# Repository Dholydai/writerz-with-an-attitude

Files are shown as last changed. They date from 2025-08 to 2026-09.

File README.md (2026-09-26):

# writerz-with-an-attitude
Human-factored Post-Mechanical writing instruments designed for and approved by 'Writerz With an Attitude'.

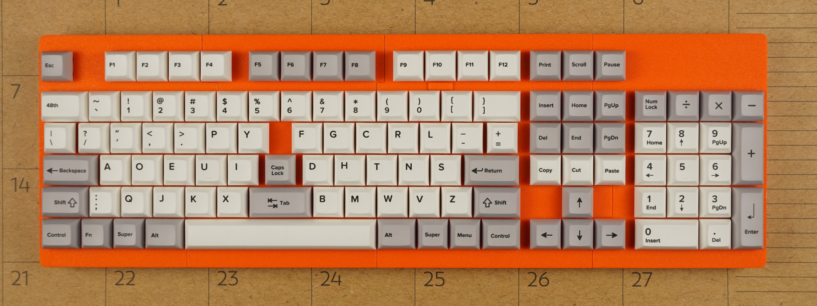
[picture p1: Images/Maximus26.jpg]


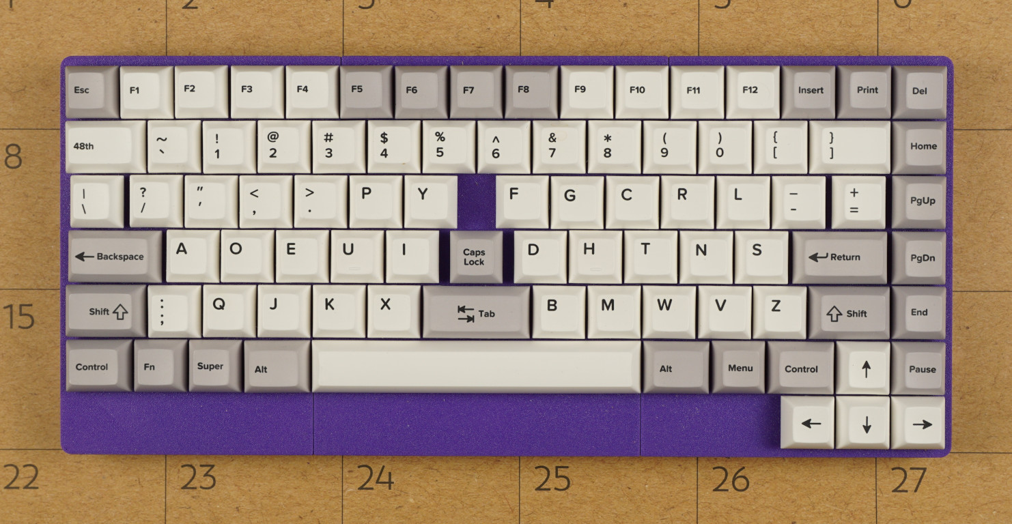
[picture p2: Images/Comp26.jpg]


Why are nascent writers, born in the third decade of the 21st century, being shackled to a 152-year-old 19th-Century mechanical typewriter interface?

I have used a Dvorak keyboard for thirty-five years. After two decades of typing, bad pains developed in my left hand and wrist. Analyzing 
my breakdown, I concluded that the physical layout of keys on conventional keyboards forces unnatural movements.

The typewriter keyboard is injurious, as evidenced by the long history of 'typists' developing carpal tunnel syndrome, including myself.

I designed the 'Dvorak 2026' to place the keys where the fingers of my two hands expect them to be. No more pain, writing is fun.

I contend that the Post-Mechanical variants establish a 'Nuevo Teclado Universal' standard. These human-factored designs will fit in currently produced
laptop PC cases. The forty-eight character keys make the keyboards ISO compliant, compatible with European languages.

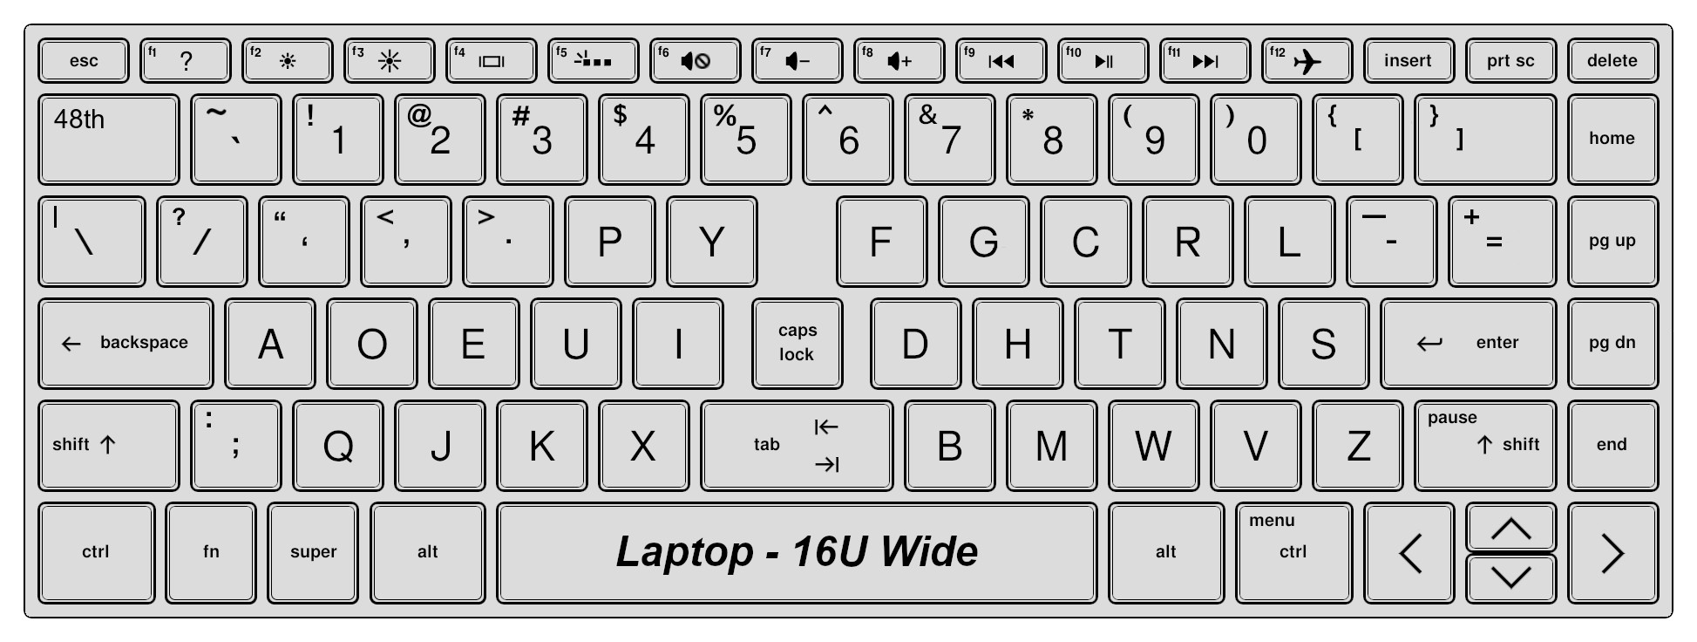
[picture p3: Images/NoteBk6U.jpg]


I have created ISO compliant firmware, and designed Windows drivers for six European languages, so far. Work on Lixux keyd configurations will
begin. Apple drivers are not my wheelhouse. Collaboration from those who can write Apple drivers is expected.

Single-hand writers should have use of modern writing instruments. After World War 2 ended, LCDR Dvorak designed two practical single-hand letter 
schemes for the typewriter that enabled disabled veterans to type comfortably.

My new compact single-hand keyboard designs have a few notable tweaks, but do not stray far from the original designs. Both variants now share 
the same letter scheme. The left-hand and right-hand keyboards are mirror images of each other.

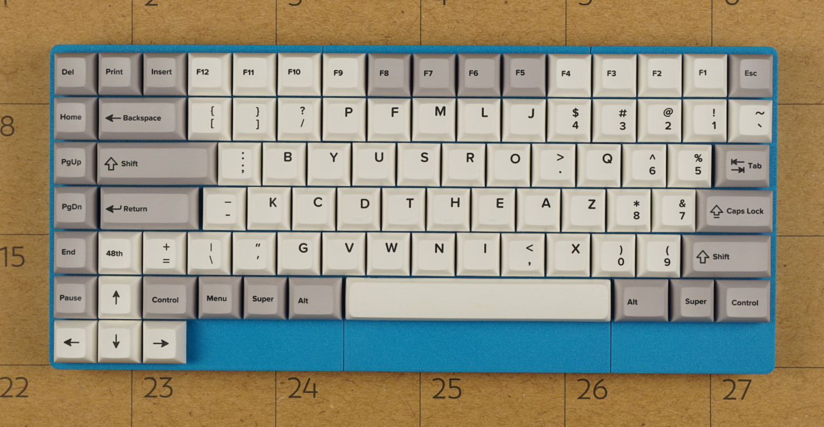
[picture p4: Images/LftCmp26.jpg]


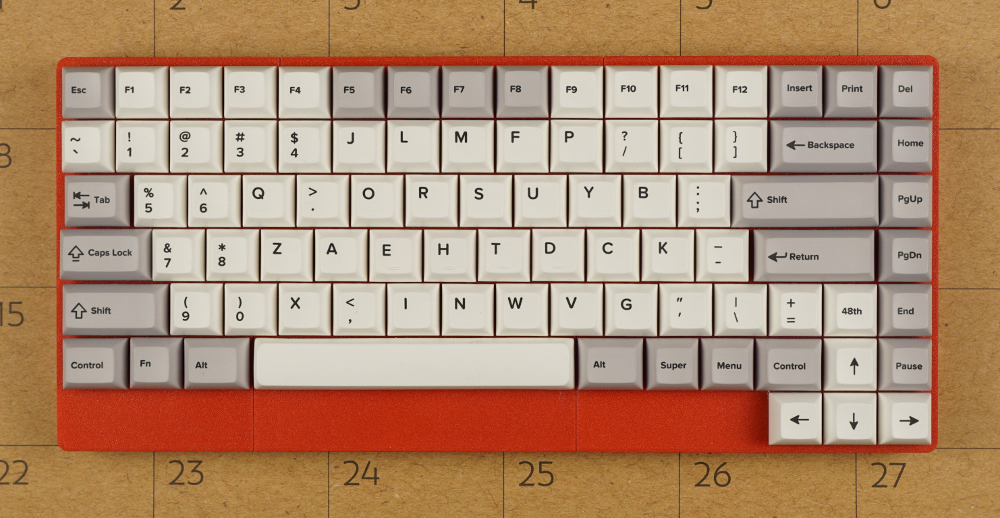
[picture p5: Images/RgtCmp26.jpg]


Quality of key switches:

Cherry MX switches have great quality. Never had a problem with them. I build all of my keyboards with Cherry switches. Less costly switches from other
manufacturers that I have tried are not shaped consistantly. Those switches would not fit the tight tolerances of my case tops. The stems tilted this
way and that way.

Availability of keycap sets:

I have been subsituting common keycaps sizes for the exotic sizes required. I bought large XDA keycap sets, and relabeled selected keycaps with 
keyboard stickers as needed.

Finding a 6U spacebar is difficult. My source makes spacebars with the stem 1\2U offset. I have designed alternate case top sections to accommodate that
spacebar. My PCBs have a dual position switch footprint to accommodate either centered or offset spacebar switch.

YUZU... In May 2025 I found a die-sub keycap manufacturer that makes one-off custom sets. The Prusa orange Maxmius above is populated by one of the many
austere sets I have created. I have designed and purchased nine keycaps sets from YUZU, including Spanish(Spain), Portuguese(Brazil), and BÉPO(France).

YUZU custom keycaps will make any die-sub keycap set that your heart desires. Common sizes still have to be sustituted. Being able to choose keycap 
sizes, colors, and legends is wonderful. Love the new Penguin Slide Belly (PBS) profile keycaps. Great price and quality.

The French, Spanish, and Brazilian keyboards were built in late August 2026.

3D printer problems:

The first Maximus case would not sit flat on a desktop. After a month of struggle to solve the problem, I reluctantly concluded that:

1. My Voron Trident 350 cannot print case top sections with enough quality. The X- to Y-axis geometry is not consistently 90 degrees.
2. This problem is not Voron Designs' shortcoming, it is intrinsic to all Core-XY printers. This is due to the quick changes of direction that temporarily stretch the long XY belts during operation; that slop gets worse as printer size increases.
3. 'Bed slingers' use much shorter belts, they do not have this built-in fault.

My Prusa MK3.5 has a new companion... a Prusa MK4S. The new printer makes parts that match-up perfectly with the MK 3.5 parts. Print times for a case
bottom section changed dramatically: from 3hs 15 mins to 1 hr 45 mins. I am now a committed Prusa fanatic.

Link to my repo of custom KiCad libraries: [MX Switch Custom](https://github.com/Dholydai/mx-switch-custom)

Ronald Earl Walker - Inventor of the Post-Mechanical Keyboard

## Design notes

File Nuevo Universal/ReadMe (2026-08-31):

Nuevo Universal Keyboard:

The Dvorak typewriter keyboard letter scheme is designed for writing using two-hands. It is apposite for writing any language that uses the Latin, Cyrillic or Greek script.

Note: The US(English) Post-Mechanical keyboard is hardwired to use the native QWERTY driver. Users should not install the America-ISO driver,

Note: Linux OS users of the US(English) Post-Mechanical will use the native US-QWERTY driver.

The US English ISO driver was written to facilitate developing European language drivers (the locations of the '[ ]' and '- =' key sets are swapped).

The Post-Mechanical Dvorak 2025 keymap has 48 character keys. This makes it compatible with ISO keyboards.

I have created and tested Windows drivers for several European languages. Linux drivers will be developed next, Apple is not my wheelhouse.

Ronald Earl Walker

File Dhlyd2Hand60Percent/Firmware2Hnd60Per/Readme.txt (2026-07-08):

The Post-Mechanical Ambidextrous Sixty has three status LEDs mounted in MX switches. The 'Caps Lock' works as as expected, the Left- and Right-Hand 'Fn' key LEDS do not.

The layers (Standard, Left-Hand and Right-Hand) are functioning correctly. The right 'Fn' key selects Left-Hand and toggles back to Standard when pressed again.
Visa versa for the left 'Fn' key. Good to go.

The status LEDs do light up, but not in current operation as status indicators by the firmware. KMK can surely be configured or tweaked to do the job.

I am not a coder. I cannot figure out how make this work. KMK does provide for 'Layer Status' indication using the background RGB LEDs, not discrete LEDS.

I build writing instruments, not entertainment centers. RGB backgroud LEDs are candy that is craved by ADHD lemmings in need of stimulus.

Collaboration would be greatly appreciated.

Ronald Earl Walker

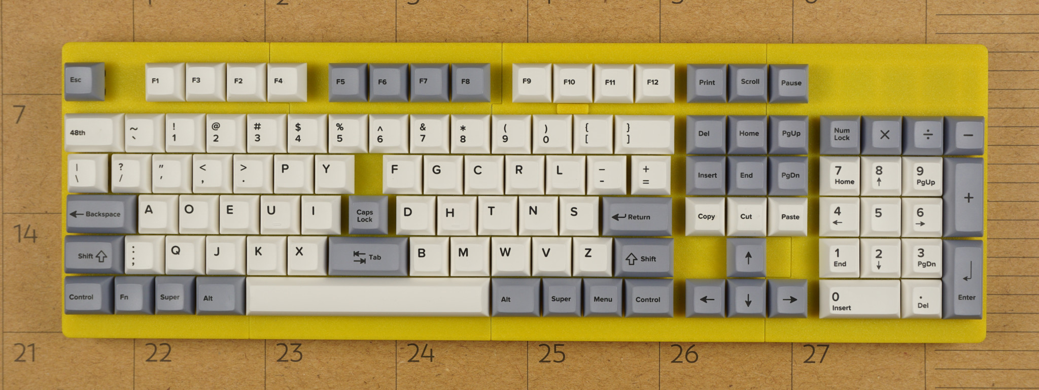
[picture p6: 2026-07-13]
Images/Maximus26B.jpg

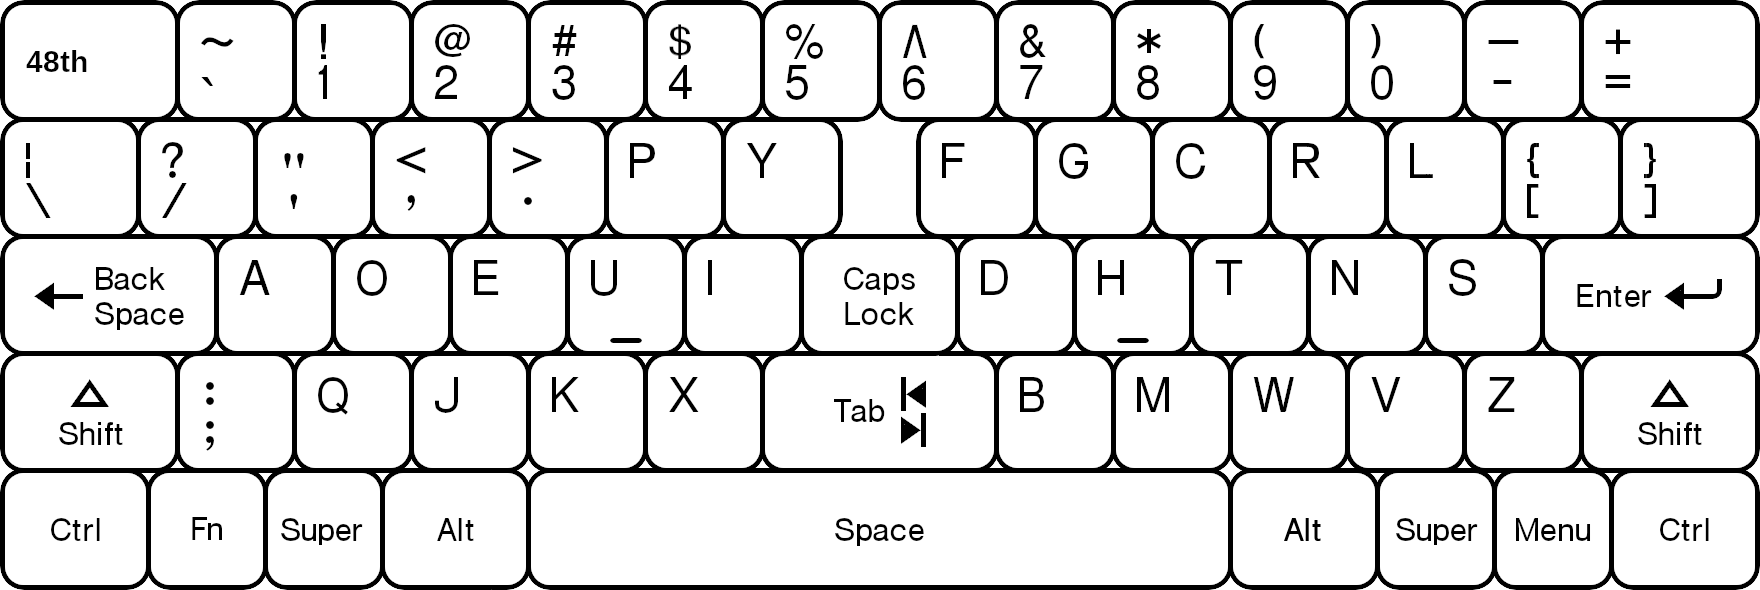
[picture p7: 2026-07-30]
Nuevo Universal/America-ISO/BlkQX1-ENGiso.png

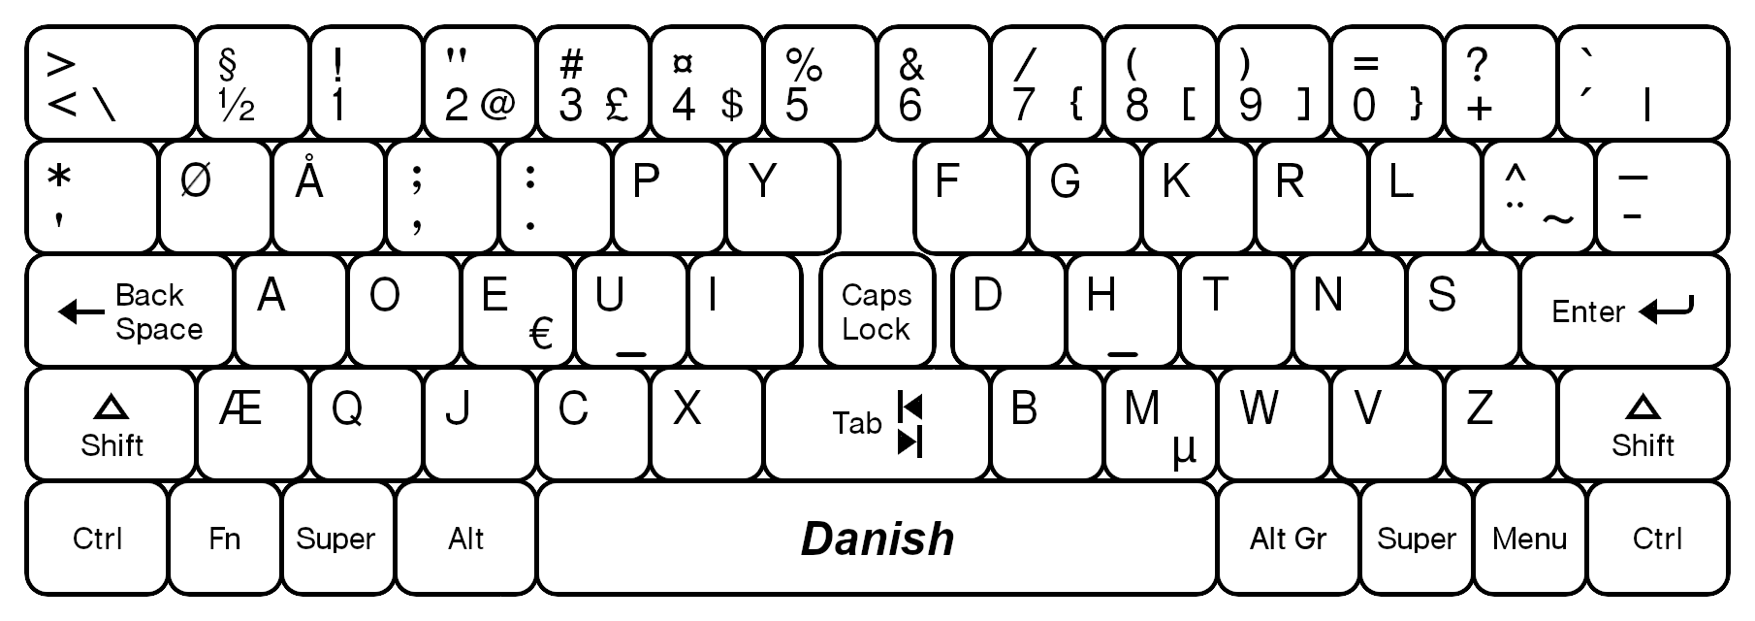
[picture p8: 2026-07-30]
Nuevo Universal/Denmark/BlkQX1-Dane.png

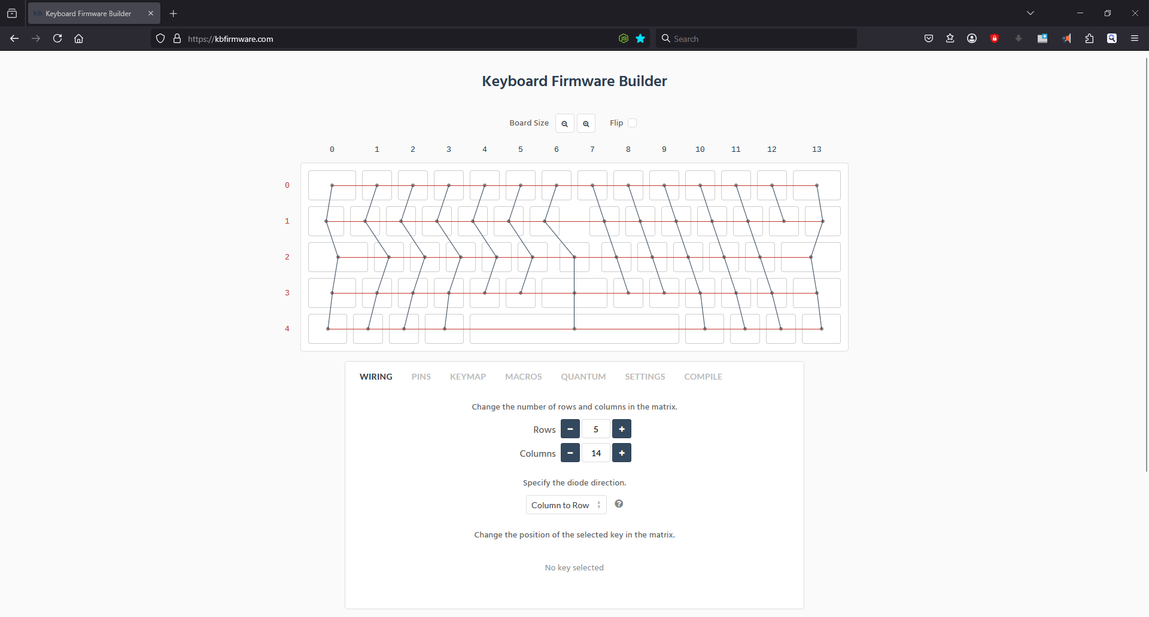
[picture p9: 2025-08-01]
Matrix/Dhlyd2Hnd60.png

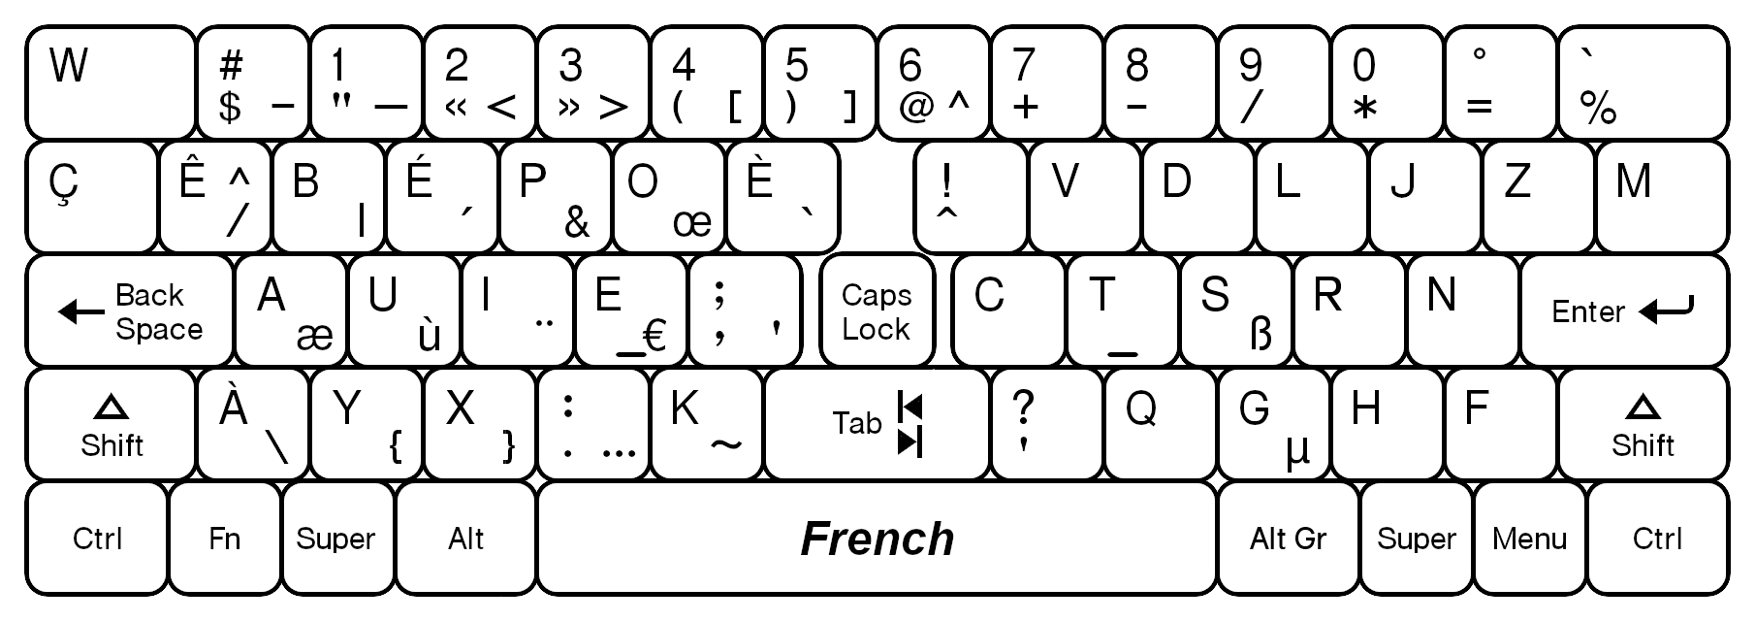
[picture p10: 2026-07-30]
Nuevo Universal/France-BÉPO/BlkQX1-French.png

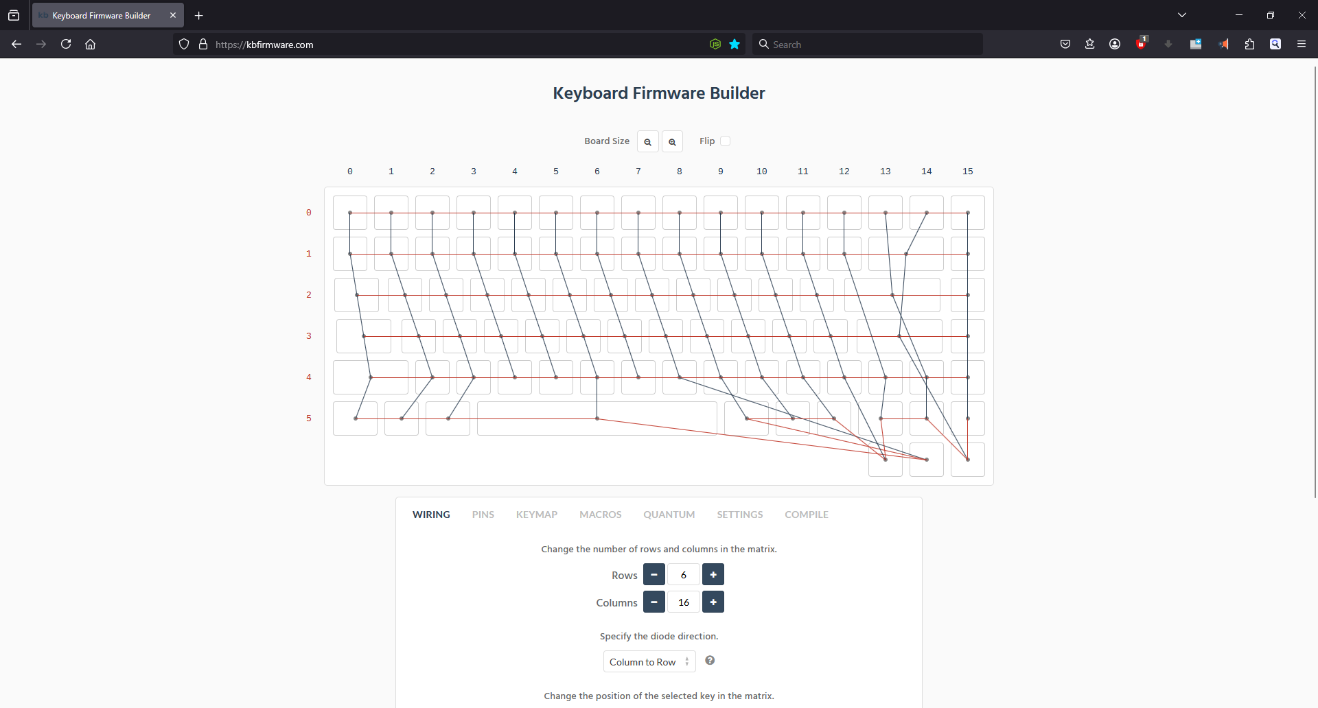
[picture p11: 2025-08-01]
Matrix/DhlydRightCmp.png

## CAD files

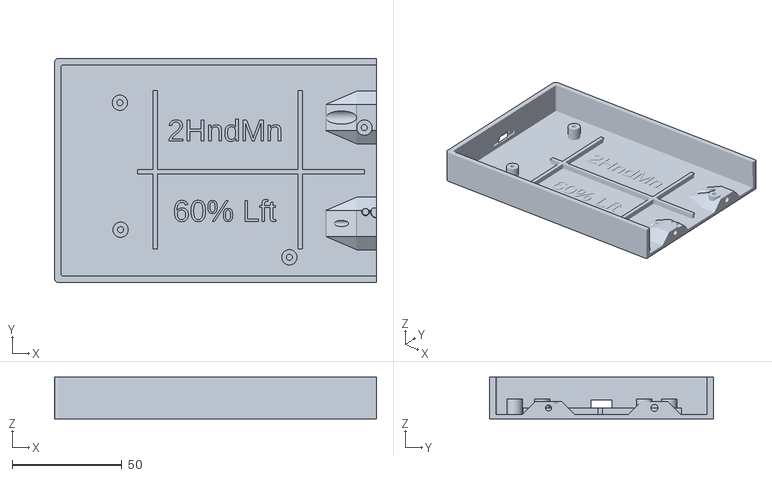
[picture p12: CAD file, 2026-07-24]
Dhlyd2Hand60Percent/Case2Hnd60Per/Minimal/SixtyMiniLft.stl
146.7 x 102.2 x 19.0

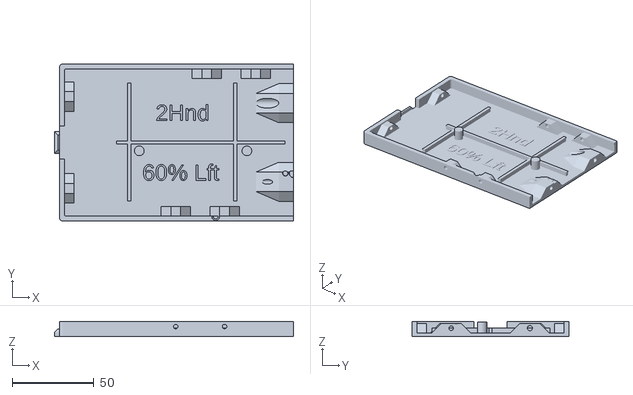
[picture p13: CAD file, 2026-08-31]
Dhlyd2Hand60Percent/Case2Hnd60Per/Stl/SixtyBtmLft.stl
146.6 x 96.2 x 9.00

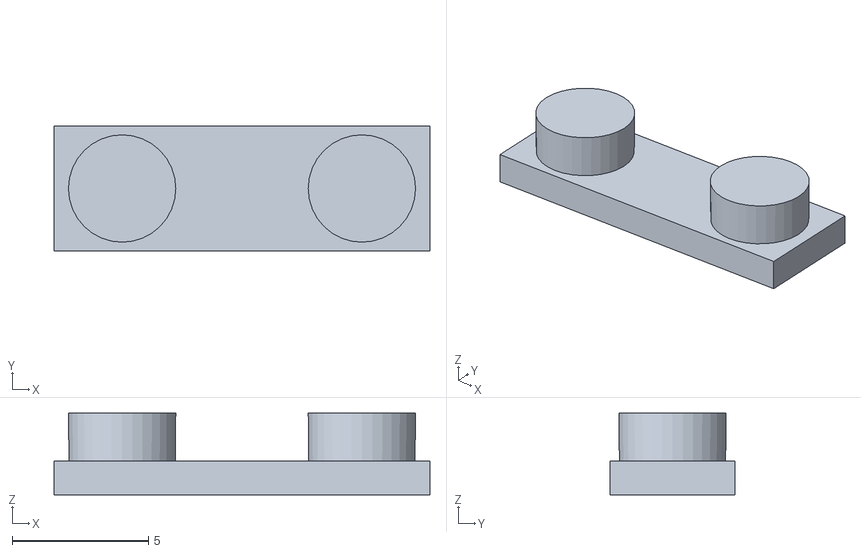
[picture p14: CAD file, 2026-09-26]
Dhlyd2HandCompact/Case2HndComp/Stl/ResetRunCvrCmp.stl
13.8 x 4.60 x 3.00

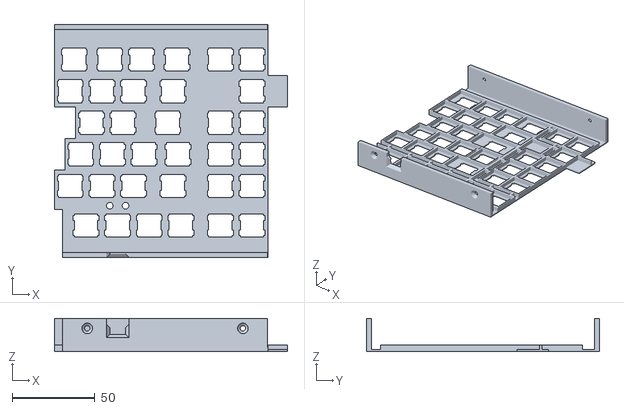
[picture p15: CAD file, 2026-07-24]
Dhlyd2HandMaximus/Case2HndMaximus/Stl/Max2HndTopMid2.stl
140.5 x 140.4 x 20.0

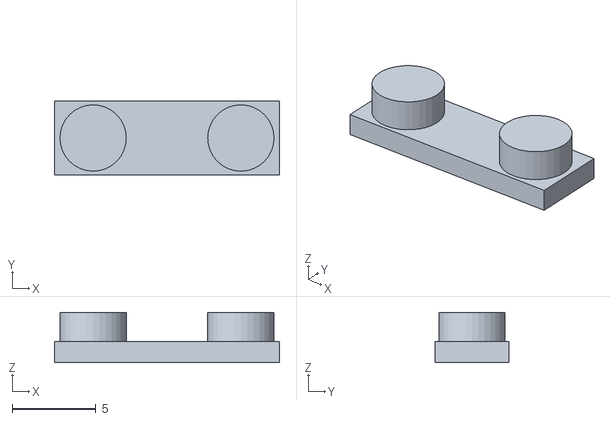
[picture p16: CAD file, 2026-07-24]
DhlydLeftCompact/CaseLeftHndComp/Stl/ResetRunCvrLR.stl
13.4 x 4.40 x 3.00

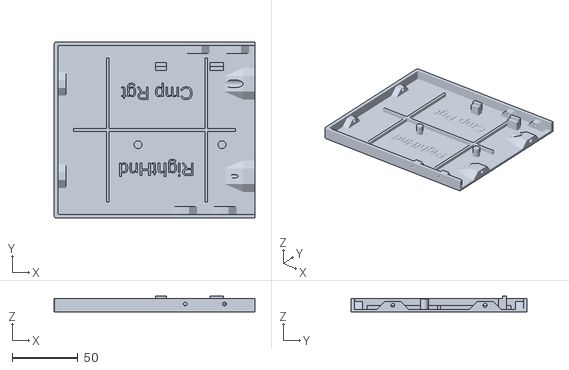
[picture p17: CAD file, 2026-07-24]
DhlydRightCompact/CaseRightHndComp/Stl/CompRightBtmRgt.stl
153.1 x 134.3 x 12.0

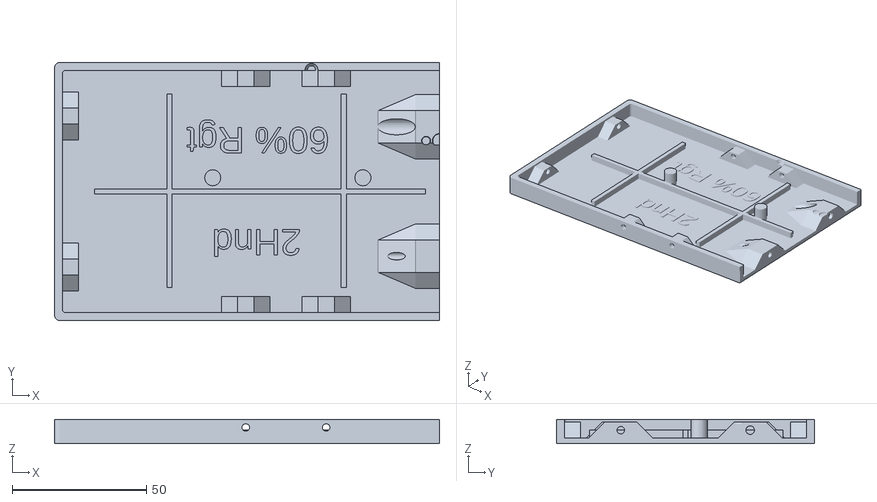
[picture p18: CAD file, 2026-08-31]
Dhlyd2Hand60Percent/Case2Hnd60Per/Stl/SixtyBtmRgt.stl
143.6 x 96.2 x 9.00

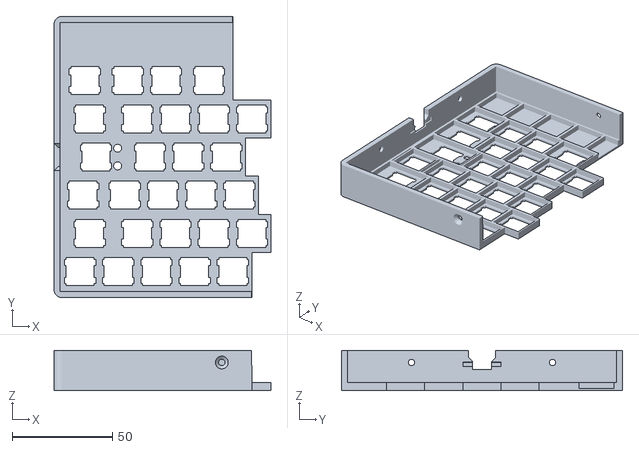
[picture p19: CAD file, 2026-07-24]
Dhlyd2HandCompact/Case2HndComp/Stl/Comp2HndTopLft.stl
108.3 x 140.4 x 20.0

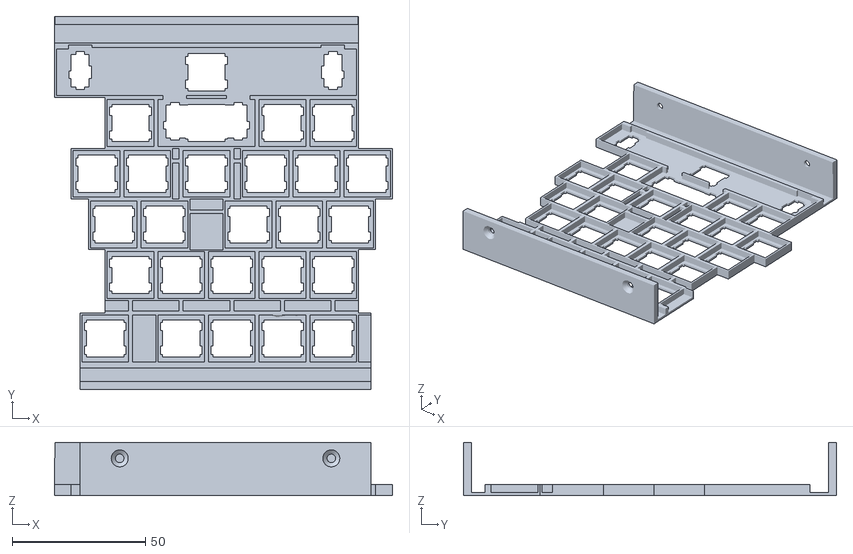
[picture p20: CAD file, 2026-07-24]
Dhlyd2HandMaximus/Case2HndMaximus/Stl/Max2HndTopMid1_Center.stl
127.1 x 140.3 x 20.0

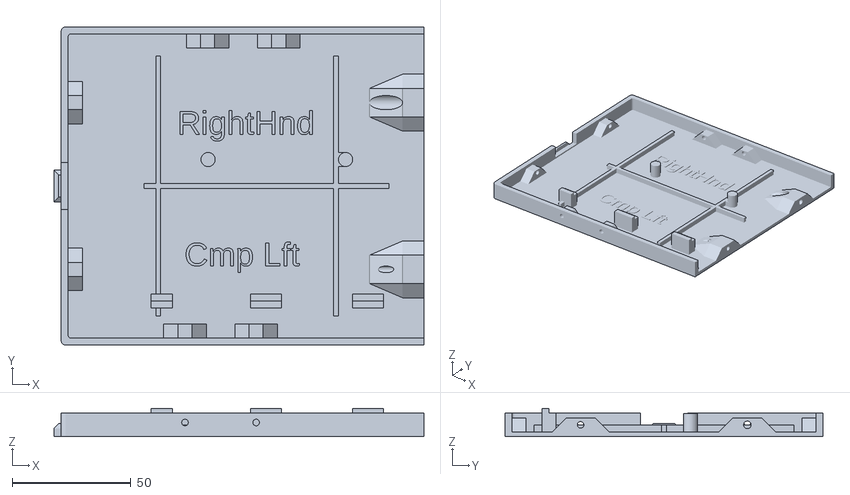
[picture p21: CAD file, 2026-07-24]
DhlydRightCompact/CaseRightHndComp/Stl/CompRightBtmLft.stl
156.1 x 134.4 x 12.0

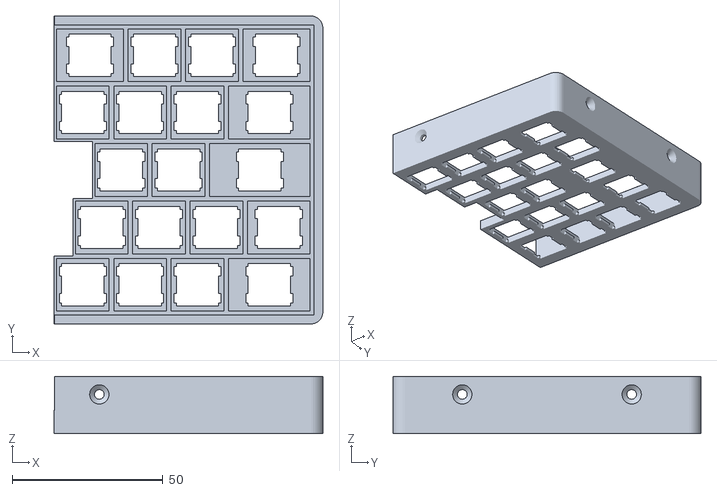
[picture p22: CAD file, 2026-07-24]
Dhlyd2Hand60Percent/Case2Hnd60Per/Stl/SixtyTopRgt.stl
89.2 x 102.2 x 19.0

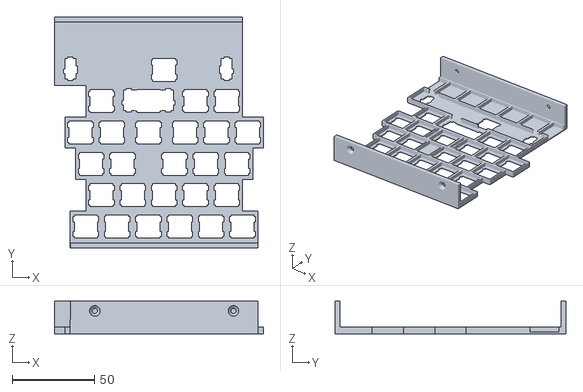
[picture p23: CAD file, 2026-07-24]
Dhlyd2HandCompact/Case2HndComp/Stl/Comp2HndTopMid_Offset.stl
127.1 x 140.4 x 20.0

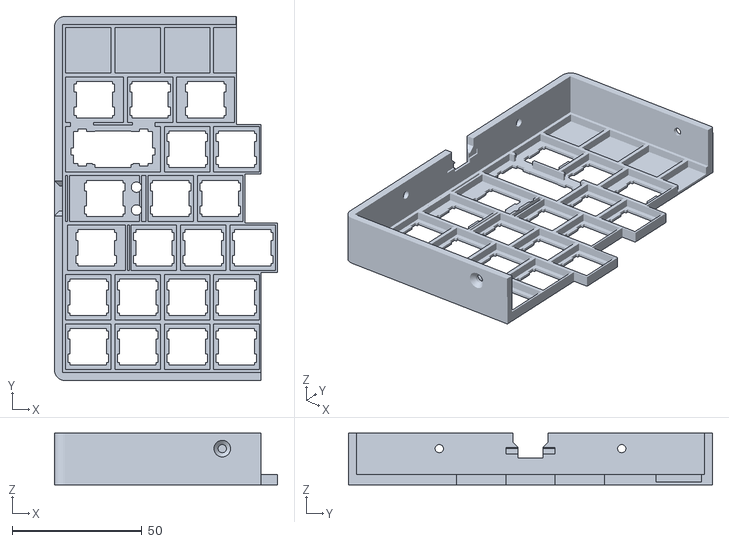
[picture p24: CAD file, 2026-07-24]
DhlydRightCompact/CaseRightHndComp/Stl/CompRightTopLft.stl
86.0 x 140.4 x 20.0

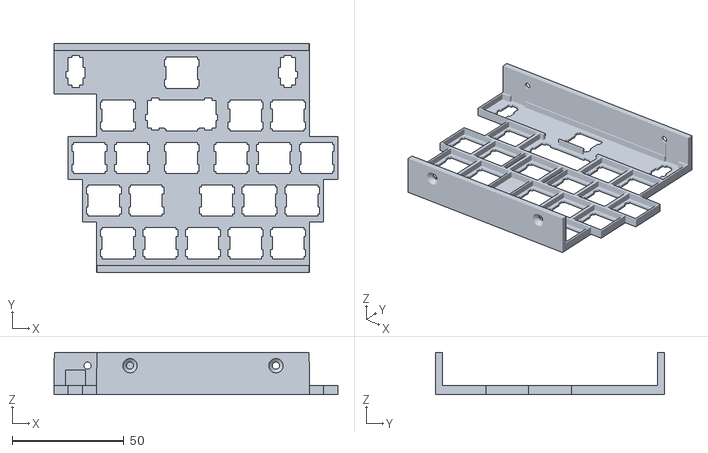
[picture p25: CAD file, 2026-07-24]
Dhlyd2Hand60Percent/Case2Hnd60Per/Stl/SixtyTopMid_Center.stl
127.1 x 102.2 x 19.0

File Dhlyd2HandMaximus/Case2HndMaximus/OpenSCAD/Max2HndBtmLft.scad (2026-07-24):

// Dholydai: 05 May 2025 10mm Z and X=143.20833...
// Add 0.1mm to the top & bottom screw holder's X axis, compensating for shrinkage.
// Add shallow angle cuts to the sidewall butt faces, compensating for printer artifacts.
// Reduced ribs Z 10 Jul 2026

translate([51,36,0])
rotate([0,0,0])
linear_extrude(2.6)
text("Max Lft",size=10,font="Microsoft Sans Serif");
translate([57,91,0])
rotate([0,0,0])
linear_extrude(2.6)
text("2Hnd",size=10,font="Microsoft Sans Serif");

//BASE
$fn=32;

difference(){
//Deck
    union() {
        translate([2,2,0])
            cube([141.2,130.35,2]);
        translate([2,0,0])
            cube([141.2,2,2]);   
        translate([2,132.35,0])
            cube([141.2,2,2]);
        translate([0,2,0])
            cube([2,130.35,2]);    
        translate([2,2,0])
            cylinder(h=2,r1=2,r2=2);
        translate([2,132.35,0])
            cylinder(h=2,r1=2,r2=2);
//Sidewall
translate([0,2,2])
    cube([3,130.35,8]);
translate([2,131.35,2])
    cube([141.2,3,8]);
translate([2,0,2])
    cube([141.2,3,8]);
//SW Corners Outside   
translate([2,2,6])
    rotate([0,0,180]){
    rotate_extrude( angle=90)
        translate([1,0,0])
            square([2,8], center=true);
}
translate([2,132.35,6])
    rotate([0,0,90]){
    rotate_extrude( angle=90)
        translate([1,0,0])
            square([2,8], center=true);
}        
//SW Corners Inside   
translate([4,4,6])
    rotate([0,0,180]){
    rotate_extrude( angle=90)
        translate([2,0,0])
            square([2,8], center=true);
}
translate([4,130.3125,6])
    rotate([0,0,90]){
    rotate_extrude( angle=90)
        translate([2,0,0])
            square([2,8], center=true);        
    }
//Screw Reenforcement
//Side
translate([3,41,2]){
    rotate([0,0,270])
             union() { 
            translate([6,0,0])
                cube([6,6,6]);            
polyhedron(points=[[0,0,0], [6,0,0], [6,6,0], [0,6,0], [6,0,6], [6,6,6]],
    faces=[[0,1,2,3],[1,4,5,2],[0,3,5,4],[0,4,1],[3,2,5]]
    );
polyhedron(points=[[12,0,0], [18,0,0], [18,6,0], [12,6,0], [12,0,6], [12,6,6]],
    faces=[[0,1,2,3],[1,4,5,2],[0,3,5,4],[0,4,1],[3,2,5]]
    );
  }
}          
translate([3,111.3125,2]){
    rotate([0,0,270])
             union() { 
            translate([6,0,0])
                cube([6,6,6]);            
polyhedron(points=[[0,0,0], [6,0,0], [6,6,0], [0,6,0], [6,0,6], [6,6,6]],
    faces=[[0,1,2,3],[1,4,5,2],[0,3,5,4],[0,4,1],[3,2,5]]
    );
polyhedron(points=[[12,0,0], [18,0,0], [18,6,0], [12,6,0], [12,0,6], [12,6,6]],
    faces=[[0,1,2,3],[1,4,5,2],[0,3,5,4],[0,4,1],[3,2,5]]
    );
  }
}
//SR Fore A
translate([62.225,3,2]){
    rotate([0,0,0])
             union() { 
            translate([6,0,0])
                cube([6,6,6]);            
polyhedron(points=[[0,0,0], [6,0,0], [6,6,0], [0,6,0], [6,0,6], [6,6,6]],
    faces=[[0,1,2,3],[1,4,5,2],[0,3,5,4],[0,4,1],[3,2,5]]
    );
polyhedron(points=[[12,0,0], [18,0,0], [18,6,0], [12,6,0], [12,0,6], [12,6,6]],
    faces=[[0,1,2,3],[1,4,5,2],[0,3,5,4],[0,4,1],[3,2,5]]
    );
  }
}
//SR Fore B          
translate([92.225,3,2]){
    rotate([0,0,0])
             union() { 
            translate([6,0,0])
                cube([6,6,6]);            
polyhedron(points=[[0,0,0], [6,0,0], [6,6,0], [0,6,0], [6,0,6], [6,6,6]],
    faces=[[0,1,2,3],[1,4,5,2],[0,3,5,4],[0,4,1],[3,2,5]]
    );
polyhedron(points=[[12,0,0], [18,0,0], [18,6,0], [12,6,0], [12,0,6], [12,6,6]],
    faces=[[0,1,2,3],[1,4,5,2],[0,3,5,4],[0,4,1],[3,2,5]]
    );
  }
}
//SR Aft A
translate([89.755,131.35,2]){
    rotate([0,0,180])
             union() { 
            translate([6,0,0])
                cube([6,6,6]);            
polyhedron(points=[[0,0,0], [6,0,0], [6,6,0], [0,6,0], [6,0,6], [6,6,6]],
    faces=[[0,1,2,3],[1,4,5,2],[0,3,5,4],[0,4,1],[3,2,5]]
    );
polyhedron(points=[[12,0,0], [18,0,0], [18,6,0], [12,6,0], [12,0,6], [12,6,6]],
    faces=[[0,1,2,3],[1,4,5,2],[0,3,5,4],[0,4,1],[3,2,5]]
    );
  }
}
//SR Aft B         
translate([119.755,131.35,2]){
    rotate([0,0,180])
             union() { 
            translate([6,0,0])
                cube([6,6,6]);            
polyhedron(points=[[0,0,0], [6,0,0], [6,6,0], [0,6,0], [6,0,6], [6,6,6]],
    faces=[[0,1,2,3],[1,4,5,2],[0,3,5,4],[0,4,1],[3,2,5]]
    );
polyhedron(points=[[12,0,0], [18,0,0], [18,6,0], [12,6,0], [12,0,6], [12,6,6]],
    faces=[[0,1,2,3],[1,4,5,2],[0,3,5,4],[0,4,1],[3,2,5]]
    );
   }
 }      
}
//Screw Holes Side
#translate([-1,32,6]){
    rotate([0,90,0]){
         cylinder(d=2.8,h=12);      
      }
}
#translate([-1,102.3125,6]){
    rotate([0,90,0]){
         cylinder(d=2.8,h=12);      
      }
}
//Screw Holes Fore A
#translate([71.225,-1,6]){
    rotate([-90,0,0]){
         cylinder(d=2.8,h=12);      
      }
}
//SH Fore B
#translate([101.225,-1,6]){
    rotate([-90,0,0]){
         cylinder(d=2.8,h=12);      
      }
}
//Screw Holes Aft A
#translate([80.755,136,6]){
    rotate([90,0,0]){
         cylinder(d=2.8,h=12);
    }
}
//SH Aft B     
#translate([110.755,136,6]){
    rotate([90,0,0]){
         cylinder(d=2.8,h=12);      
      }
    }
//Shallow angle sidewall cuts
//Cutter Fore (right end)
#translate ([143.15,-1,0])
//                  0        1        2        3        4        5         6         7
polyhedron(points=[[0.1,0,0], [5,0,0], [5,5,0], [0.1,5,0], [0,0,10], [5,0,10], [5,5,10], [0,5,10]],
 
    faces=[[0,4,5,1],[0,3,7,4],[1,5,6,2],[2,6,7,3],[0,1,2,3],[4,7,6,5]]
              );
//Cutter Aft (right end)            
#translate ([143.15,130.35,0])
//                  0        1        2        3        4        5         6         7
polyhedron(points=[[0.1,0,0], [5,0,0], [5,5,0], [0.1,5,0], [0,0,10], [5,0,10], [5,5,10], [0,5,10]],
 
    faces=[[0,4,5,1],[0,3,7,4],[1,5,6,2],[2,6,7,3],[0,1,2,3],[4,7,6,5]]
              );          
  }
//Cross Ribs
translate([14.9,66.175,2])
    cube([115,2,3]);
translate([38,12.3,2])
    cube([2,109.75,3]);
translate([110,12.3,2])
    cube([2,109.75,3]);
//Mid Supports
translate([66.5,66.3,2])
    cylinder(h=7.9,r1=3,r2=3);
translate([130,66.3,2])
    cylinder(h=7.9,r1=3,r2=3);
//PCB Bottom Left    
translate([44,5,2])
    cube([13,6,7.9]);
translate([44,5,9.9])
    #cube([13,3,2]);
translate([104,5,2])
    cube([13,6,7.9]);
translate([104,5,9.9])
    #cube([13,3,2]);
    
//Mechanical Union
//Top Joint
translate([120.2,113.35,2]){
    rotate([0,0,-90])
        difference() {
            union() {   
                translate([6,14,0])
                    cube([12,9,6]);
//Right
polyhedron(points=[[18,14,0], [24,14,0], [24,23,0], [18,23,0], [18,14,6], [18,23,6]],
    faces=[[0,1,2,3],[1,4,5,2],[0,3,5,4],[0,4,1],[3,2,5]]
              );
//Left
polyhedron(points=[[0,14,0], [6,14,0], [6,23,0], [0,23,0], [6,14,6], [6,23,6]],
    faces=[[0,1,2,3],[1,4,5,2],[0,3,5,4],[0,4,1],[3,2,5]]
              );
//Flip                  0       1           2          3        4           5
polyhedron(points=[[6,0,0], [18,0,0], [18,14,0], [6,14,0], [6,14,6], [18,14,6]],
    faces=[[0,1,2,3],[5,4,3,2],[0,4,5,1],[0,3,4],[5,2,1]]
              );
polyhedron(points=[[18,14,0], [18,0,0], [24,14,0], [18,14,6]],
    faces=[[0,1,2],[0,2,3],[0,3,1],[1,3,2]]
              );
polyhedron(points=[[0,14,0], [6,14,0], [6,0,0], [6,14,6]],
    faces=[[0,2,1],[0,1,3],[1,2,3],[0,3,2]]
              );
    }
     translate([12,0,3]){
     rotate([-90,0,0])
        #cylinder(d=3.2,h=26);
        
        }
    translate([12,0,3]){
     rotate([-90,0,0])
       #cylinder(d=6,h=14);
        
        }
    }
}

//Bottom Joint
translate([120.2,45,2]){
    rotate([0,0,-90])
        difference() {
            union() {   
                translate([6,14,0])
                    cube([12,9,6]);
//Right
polyhedron(points=[[18,14,0], [24,14,0], [24,23,0], [18,23,0], [18,14,6], [18,23,6]],
    faces=[[0,1,2,3],[1,4,5,2],[0,3,5,4],[0,4,1],[3,2,5]]
              );
//Left
polyhedron(points=[[0,14,0], [6,14,0], [6,23,0], [0,23,0], [6,14,6], [6,23,6]],
    faces=[[0,1,2,3],[1,4,5,2],[0,3,5,4],[0,4,1],[3,2,5]]
              );
//Flip                  0       1           2          3        4           5
polyhedron(points=[[6,0,0], [18,0,0], [18,14,0], [6,14,0], [6,14,6], [18,14,6]],
    faces=[[0,1,2,3],[5,4,3,2],[0,4,5,1],[0,3,4],[5,2,1]]
              );
polyhedron(points=[[18,14,0], [18,0,0], [24,14,0], [18,14,6]],
    faces=[[0,1,2],[0,2,3],[0,3,1],[1,3,2]]
              );
polyhedron(points=[[0,14,0], [6,14,0], [6,0,0], [6,14,6]],
    faces=[[0,2,1],[0,1,3],[1,2,3],[0,3,2]]
              );
    }
     translate([12,0,3]){
     rotate([-90,0,0])
        #cylinder(d=2.8,h=26);
        
        }
    translate([12,0,3]){
     rotate([-90,0,0])
       *cylinder(d=6,h=14);
        
        }
    }
}
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

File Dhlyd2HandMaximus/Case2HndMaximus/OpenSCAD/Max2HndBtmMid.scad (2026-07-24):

// Dholydai: 05 May 2025 10mm Z and X=143.20833...
// Add 0.6mm to the section's X axis, distributed 0.3mm to each side (no movement of the screw holders), compensating for shrinkage (x=143.8)
// Add shallow angle cuts to the sidewall butt faces, compensating for printer artifacts.
// Add 20mm sidewall cut and threshold for U1 port.
// Change USB port wedge to truncated,reduced ribs Z 10 Jul 2026

// Txt
translate([45,36,0])
rotate([0,0,0])
linear_extrude(2.6)
text("Max Mid",size=10,font="Microsoft Sans Serif");
translate([55.3,91,0])
rotate([0,0,0])
linear_extrude(2.6)
text("2Hnd",size=10,font="Microsoft Sans Serif");
//BASE

$fn=32;
difference(){
//Deck
    union() {
        translate([0,2,0])
            cube([143.8,130.35,2]);
        translate([0,0,0])
            cube([143.8,2,2]);
        translate([0,132.35,0])
            cube([143.8,2,2]);    
//Sidewall
translate([0,131.35,2])
    cube([85.8,3,8]);
translate([105.8,131.35,2])
    cube([38,3,8]);
translate([0,0,2])
    cube([143.8,3,8]);
// Center Support
translate([66.1,5,2])
    cube([13,6,7.9]);
translate([66.1,5,9.9])
    #cube([13,3,2]);    
//Screw Reenforcement
//SR Fore C
translate([33.625,3,2]){
    rotate([0,0,0])
             union() { 
            translate([6,0,0])
                cube([6,6,6]);            
polyhedron(points=[[0,0,0], [6,0,0], [6,6,0], [0,6,0], [6,0,6], [6,6,6]],
    faces=[[0,1,2,3],[1,4,5,2],[0,3,5,4],[0,4,1],[3,2,5]]
    );
polyhedron(points=[[12,0,0], [18,0,0], [18,6,0], [12,6,0], [12,0,6], [12,6,6]],
    faces=[[0,1,2,3],[1,4,5,2],[0,3,5,4],[0,4,1],[3,2,5]]
    );
  }
}
//SR Fore D          
translate([63.625,3,2]){
    rotate([0,0,0])
             union() { 
            translate([6,0,0])
                cube([6,6,6]);            
polyhedron(points=[[0,0,0], [6,0,0], [6,6,0], [0,6,0], [6,0,6], [6,6,6]],
    faces=[[0,1,2,3],[1,4,5,2],[0,3,5,4],[0,4,1],[3,2,5]]
    );
polyhedron(points=[[12,0,0], [18,0,0], [18,6,0], [12,6,0], [12,0,6], [12,6,6]],
    faces=[[0,1,2,3],[1,4,5,2],[0,3,5,4],[0,4,1],[3,2,5]]
    );
  }
}
//SR Aft C
translate([56.3875,131.35,2]){
    rotate([0,0,180])
             union() { 
            translate([6,0,0])
                cube([6,6,6]);            
polyhedron(points=[[0,0,0], [6,0,0], [6,6,0], [0,6,0], [6,0,6], [6,6,6]],
    faces=[[0,1,2,3],[1,4,5,2],[0,3,5,4],[0,4,1],[3,2,5]]
    );
polyhedron(points=[[12,0,0], [18,0,0], [18,6,0], [12,6,0], [12,0,6], [12,6,6]],
    faces=[[0,1,2,3],[1,4,5,2],[0,3,5,4],[0,4,1],[3,2,5]]
    );
  }
}
//SR Aft D          
translate([86.3875,131.35,2]){
    rotate([0,0,180])
             union() { 
            translate([6,0,0])
                cube([6,6,6]);            
polyhedron(points=[[0,0,0], [6,0,0], [6,6,0], [0,6,0], [6,0,6], [6,6,6]],
    faces=[[0,1,2,3],[1,4,5,2],[0,3,5,4],[0,4,1],[3,2,5]]
    );
polyhedron(points=[[12,0,0], [18,0,0], [18,6,0], [12,6,0], [12,0,6], [12,6,6]],
    faces=[[0,1,2,3],[1,4,5,2],[0,3,5,4],[0,4,1],[3,2,5]]
    );
   }
  }     
}
//Dimensions Top Case (Half-Wide)
//X=177.3312 Y=126.0625
//Screw Holes Fore C
#translate([42.625,-1,6]){
    rotate([-90,0,0]){
         cylinder(d=2.8,h=12);      
  }
}
//SH Fore D
#translate([72.75,-1,6]){
    rotate([-90,0,0]){
         cylinder(d=2.8,h=14);      
  }
}
//Screw Holes Aft C
#translate([47.3875,136,6]){
    rotate([90,0,0]){
         cylinder(d=2.8,h=12);
  }
}
//SH Aft D     
#translate([77.3875,136,6]){
    rotate([90,0,0]){
         cylinder(d=2.8,h=12);      
      }
   }
//Shallow angle sidewall cuts
//Cutter Fore (left end)
#translate ([-4.95,-1,0])
//                  0        1        2        3        4        5         6         7
polyhedron(points=[[0,0,0], [4.9,0,0], [4.9,5,0], [0,5,0], [0,0,10], [5,0,10], [5,5,10], [0,5,10]],
 
    faces=[[0,4,5,1],[0,3,7,4],[1,5,6,2],[2,6,7,3],[0,1,2,3],[4,7,6,5]]
              );
//Cutter Aft (left end)            
#translate ([-4.95,130.35,0])
//                  0        1        2        3        4        5         6         7
polyhedron(points=[[0,0,0], [4.9,0,0], [4.9,5,0], [0,5,0], [0,0,10], [5,0,10], [5,5,10], [0,5,10]],
 
    faces=[[0,4,5,1],[0,3,7,4],[1,5,6,2],[2,6,7,3],[0,1,2,3],[4,7,6,5]]
              );
//Cutter Fore (right end)
#translate ([143.75,-1,0])
//                  0        1        2        3        4        5         6         7
polyhedron(points=[[0.1,0,0], [5,0,0], [5,5,0], [0.1,5,0], [0,0,10], [5,0,10], [5,5,10], [0,5,10]],
 
    faces=[[0,4,5,1],[0,3,7,4],[1,5,6,2],[2,6,7,3],[0,1,2,3],[4,7,6,5]]
              );
//Cutter Aft (right end)            
#translate ([143.75,130.35,0])
//                  0        1        2        3        4        5         6         7
polyhedron(points=[[0.1,0,0], [5,0,0], [5,5,0], [0.1,5,0], [0,0,10], [5,0,10], [5,5,10], [0,5,10]],
 
    faces=[[0,4,5,1],[0,3,7,4],[1,5,6,2],[2,6,7,3],[0,1,2,3],[4,7,6,5]]
              );
}
//Cross Ribs
translate([15.7,66.175,2])
    cube([110,2,3]);
translate([34.8,12.3,2])
    cube([2,109.75,3]);
translate([107.8,12.3,2])
    cube([2,109.75,3]);
//Mid Supports
translate([29.4,66.3,2])
    cylinder(h=7.9,r1=3,r2=3);
translate([111.8,66.3,2])
    cylinder(h=7.9,r1=3,r2=3);
//PCB Bottom Mid   
translate([22.1,5,2])
    cube([13,6,7.9]);
translate([22.1,5,9.9])
    #cube([13,3,2]);
translate([110.1,5,2])
    cube([13,6,7.9]);
translate([110.1,5,9.9])
    #cube([13,3,2]);    
//Measure U1 Gap
*translate([85.8,134,4])
cube(4);
*translate([105.8,134,4])
cube(4);
//USB Threshold
translate([85.8,131.35,2])
    cube([20,3,1]);           
translate([89.15,134.35,0])
    cube([13.3,3,3.5]);
translate([89.15,134.35,3.5])
//                      0           1           2           3       4       5            6          7
polyhedron(points=[[0,0,0], [13.3,0,0], [13.3,3,0], [0,3,0], [2,0,2], [11.3,0,2], [11.3,1,2],[2,1,2]],
    faces=[[0,1,2,3],[6,7,3,2],[0,4,5,1],[0,3,7,4],[5,6,2,1],[7,6,5,4]]
              );       
//Mechanical Union Left !!!
//Top Joint
translate([23,89.35,2]){
    rotate([0,0,90])
        difference() {
            union() {   
                translate([6,14,0])
                    cube([12,9,6]);
//Right
polyhedron(points=[[18,14,0], [24,14,0], [24,23,0], [18,23,0], [18,14,6], [18,23,6]],
    faces=[[0,1,2,3],[1,4,5,2],[0,3,5,4],[0,4,1],[3,2,5]]
              );
//Left
polyhedron(points=[[0,14,0], [6,14,0], [6,23,0], [0,23,0], [6,14,6], [6,23,6]],
    faces=[[0,1,2,3],[1,4,5,2],[0,3,5,4],[0,4,1],[3,2,5]]
              );
//Flip                  0       1           2          3        4           5
polyhedron(points=[[6,0,0], [18,0,0], [18,14,0], [6,14,0], [6,14,6], [18,14,6]],
    faces=[[0,1,2,3],[5,4,3,2],[0,4,5,1],[0,3,4],[5,2,1]]
              );
polyhedron(points=[[18,14,0], [18,0,0], [24,14,0], [18,14,6]],
    faces=[[0,1,2],[0,2,3],[0,3,1],[1,3,2]]
              );
polyhedron(points=[[0,14,0], [6,14,0], [6,0,0], [6,14,6]],
    faces=[[0,2,1],[0,1,3],[1,2,3],[0,3,2]]
              );
    }
     translate([12,0,3]){
     rotate([-90,0,0])
        #cylinder(d=2.8,h=26);
        
        }
    translate([12,0,3]){
     rotate([-90,0,0])
       *cylinder(d=6,h=14);
        
        }
    }
}
//Bottom Joint
translate([23,21,2]){
    rotate([0,0,90])
        difference() {
            union() {   
                translate([6,14,0])
                    cube([12,9,6]);
//Right
polyhedron(points=[[18,14,0], [24,14,0], [24,23,0], [18,23,0], [18,14,6], [18,23,6]],
    faces=[[0,1,2,3],[1,4,5,2],[0,3,5,4],[0,4,1],[3,2,5]]
              );
//Left
polyhedron(points=[[0,14,0], [6,14,0], [6,23,0], [0,23,0], [6,14,6], [6,23,6]],
    faces=[[0,1,2,3],[1,4,5,2],[0,3,5,4],[0,4,1],[3,2,5]]
              );
//Flip                  0       1           2          3        4           5
polyhedron(points=[[6,0,0], [18,0,0], [18,14,0], [6,14,0], [6,14,6], [18,14,6]],
    faces=[[0,1,2,3],[5,4,3,2],[0,4,5,1],[0,3,4],[5,2,1]]
              );
polyhedron(points=[[18,14,0], [18,0,0], [24,14,0], [18,14,6]],
    faces=[[0,1,2],[0,2,3],[0,3,1],[1,3,2]]
              );
polyhedron(points=[[0,14,0], [6,14,0], [6,0,0], [6,14,6]],
    faces=[[0,2,1],[0,1,3],[1,2,3],[0,3,2]]
              );
    }
     translate([12,0,3]){
     rotate([-90,0,0])
        #cylinder(d=3.2,h=26);
        
        }
    translate([12,0,3]){
     rotate([-90,0,0])
       #cylinder(d=6,h=14);
        
        }
    }
}
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

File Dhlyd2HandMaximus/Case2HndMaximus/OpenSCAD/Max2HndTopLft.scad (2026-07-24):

// Generated by SolidPython 1.1.3 on 2025-05-02 22:15:16
// Modified by Dholydai
// Add countersunk screw holes thru the sidewalls
// Add shallow angle cuts to the sidewall butt faces, compensating for printer artifacts.

$fn = 32;

// Check Version Change
*translate([100,26.6,16])
    cube(4);

difference() {
difference() {
	union() {
		translate(v = [0, 0, 19.4445000000]) {
			translate(v = [0, 130.6125000000, 0]) {
				translate(v = [3.5000000000, 0, 0]) {
					difference() {
						union() {
							difference() {
								union() {
									union() {
										translate(v = [214.3125000000, 0, 0]) {
											translate(v = [0, -60.4375000000, 0]) {
												minkowski() {
													cube(center = true, size = [427.6250000000, 132.3500000000, 0.5555000000]);
													cylinder(center = true, h = 0.5555000000, r = 4);
												}
											}
										}
										translate(v = [0, -119.0625000000, 0]) {
											translate(v = [0, 0, -3.5555000000]) {
												difference() {
													translate(v = [-1.5000000000, 0, 0]) {
														translate(v = [0, -1.5000000000, 0]) {
															cube(size = [431.6250000000, 122.0625000000, 4.1110000000]);
														}
													}
													cube(size = [428.6250000000, 119.0625000000, 3.0000000000]);
												}
											}
										}
										translate(v = [0.0000000000, 0, 0]) {
											translate(v = [0, 0.0000000000, 0]) {
												union() {
													translate(v = [9.5250000000, 0, 0]) {
														translate(v = [0, -9.5250000000, 0]) {
															cube(center = true, size = [19.0500000000, 19.0500000000, 1.1110000000]);
														}
													}
													translate(v = [9.5250000000, 0, 0]) {
														translate(v = [0, -9.5250000000, 0]) {
															difference() {
																translate(v = [0, 0, -1.5000000000]) {
																	cube(center = true, size = [19.0500000000, 19.0500000000, 4.1110000000]);
																}
																translate(v = [0, 0, -1.5000000000]) {
																	cube(center = true, size = [17.5500000000, 17.5500000000, 6.0000000000]);
																}
															}
														}
													}
												}
											}
										}
										translate(v = [0.0000000000, 0, 0]) {
											translate(v = [0, -19.0500000000, 0]) {
												union() {
													translate(v = [9.5250000000, 0, 0]) {
														translate(v = [0, -9.5250000000, 0]) {
															cube(center = true, size = [19.0500000000, 19.0500000000, 1.1110000000]);
														}
													}
													translate(v = [9.5250000000, 0, 0]) {
														translate(v = [0, -9.5250000000, 0]) {
															difference() {
																translate(v = [0, 0, -1.5000000000]) {
																	cube(center = true, size = [19.0500000000, 19.0500000000, 4.1110000000]);
																}
																translate(v = [0, 0, -1.5000000000]) {
																	cube(center = true, size = [17.5500000000, 17.5500000000, 6.0000000000]);
																}
															}
														}
													}
												}
											}
										}
										translate(v = [0.0000000000, 0, 0]) {
											translate(v = [0, -38.1000000000, 0]) {
												union() {
													translate(v = [9.5250000000, 0, 0]) {
														translate(v = [0, -9.5250000000, 0]) {
															cube(center = true, size = [19.0500000000, 19.0500000000, 1.1110000000]);
														}
													}
													translate(v = [9.5250000000, 0, 0]) {
														translate(v = [0, -9.5250000000, 0]) {
															difference() {
																translate(v = [0, 0, -1.5000000000]) {
																	cube(center = true, size = [19.0500000000, 19.0500000000, 4.1110000000]);
																}
																translate(v = [0, 0, -1.5000000000]) {
																	cube(center = true, size = [17.5500000000, 17.5500000000, 6.0000000000]);
																}
															}
														}
													}
												}
											}
										}
										translate(v = [0.0000000000, 0, 0]) {
											translate(v = [0, -57.1500000000, 0]) {
												union() {
													translate(v = [9.5250000000, 0, 0]) {
														translate(v = [0, -9.5250000000, 0]) {
															cube(center = true, size = [19.0500000000, 19.0500000000, 1.1110000000]);
														}
													}
													translate(v = [9.5250000000, 0, 0]) {
														translate(v = [0, -9.5250000000, 0]) {
															difference() {
																translate(v = [0, 0, -1.5000000000]) {
																	cube(center = true, size = [19.0500000000, 19.0500000000, 4.1110000000]);
																}
																translate(v = [0, 0, -1.5000000000]) {
																	cube(center = true, size = [17.5500000000, 17.5500000000, 6.0000000000]);
																}
															}
														}
													}
												}
											}
										}
										translate(v = [0.0000000000, 0, 0]) {
											translate(v = [0, -76.2000000000, 0]) {
												union() {
													translate(v = [9.5250000000, 0, 0]) {
														translate(v = [0, -9.5250000000, 0]) {
															cube(center = true, size = [19.0500000000, 19.0500000000, 1.1110000000]);
														}
													}
													translate(v = [9.5250000000, 0, 0]) {
														translate(v = [0, -9.5250000000, 0]) {
															difference() {
																translate(v = [0, 0, -1.5000000000]) {
																	cube(center = true, size = [19.0500000000, 19.0500000000, 4.1110000000]);
																}
																translate(v = [0, 0, -1.5000000000]) {
																	cube(center = true, size = [17.5500000000, 17.5500000000, 6.0000000000]);
																}
															}
														}
													}
												}
											}
										}
										translate(v = [0.0000000000, 0, 0]) {
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

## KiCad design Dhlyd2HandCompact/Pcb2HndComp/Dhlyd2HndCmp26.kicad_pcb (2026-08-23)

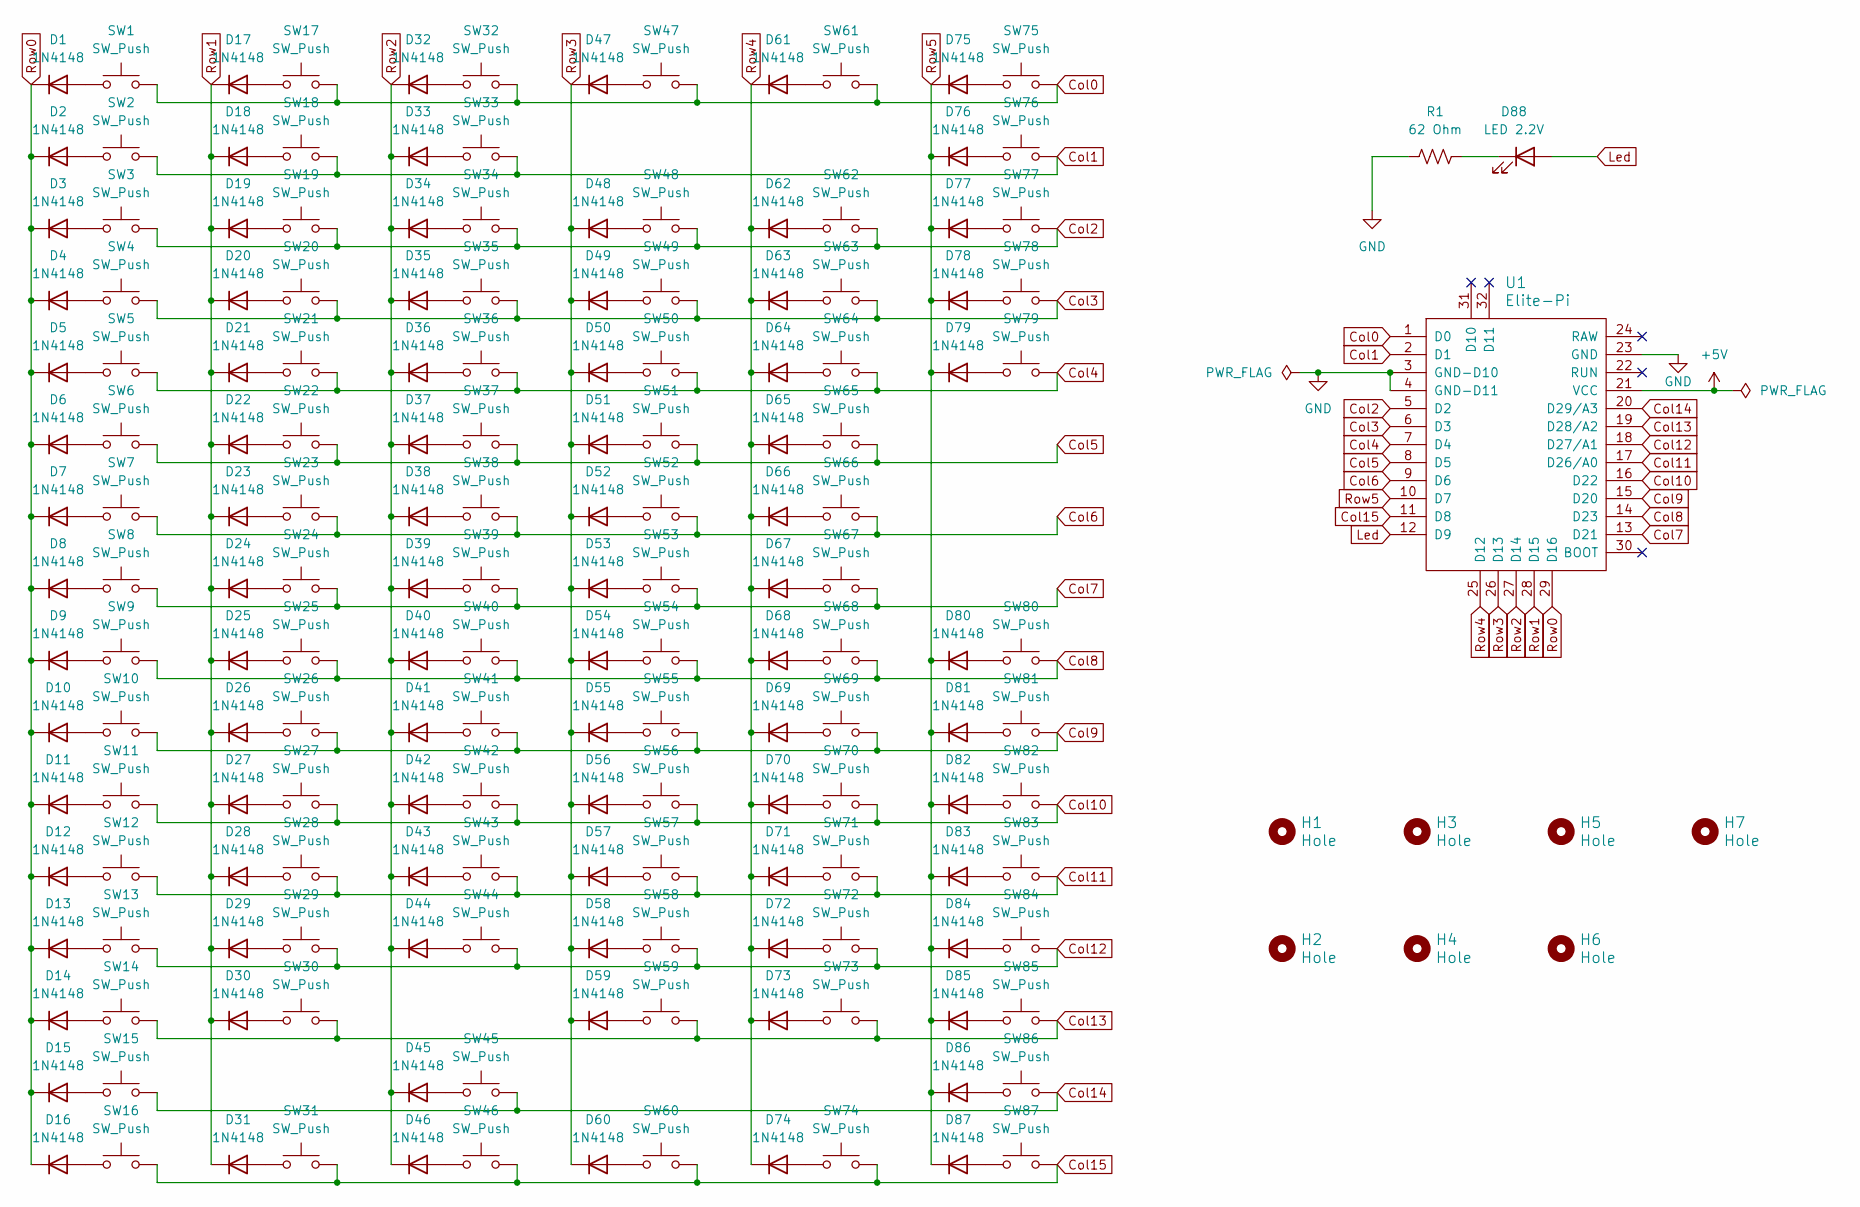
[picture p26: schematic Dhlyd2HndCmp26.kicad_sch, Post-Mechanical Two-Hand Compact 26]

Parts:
D1, D2, D3, D4, D5, D6, D7, D8, D9, D10, D11, D12, D13, D14, D15, D16, D17, D18, D19, D20, D21, D22, D23, D24, D25, D26, D27, D28, D29, D30, D31, D32, D33, D34, D35, D36, D37, D38, D39, D40, D41, D42, D43, D44, D45, D46, D47, D48, D49, D50, D51, D52, D53, D54, D55, D56, D57, D58, D59, D60, D61, D62, D63, D64, D65, D66, D67, D68, D69, D70, D71, D72, D73, D74, D75, D76, D77, D78, D79, D80, D81, D82, D83, D84, D85, D86, D87: 1N4148; D_DO-35_SOD27_P7.62mm_Horizontal
D88: LED 2.2V; SW_Ch_MX_LED_Template
H1, H2, H3, H4, H5, H6, H7: Hole; MountingHole_3.2mm_M3_Pad
R1: 62 Ohm; R_Axial_DIN0207_L6.3mm_D2.5mm_P10.16mm_Horizontal
SW1, SW2, SW3, SW4, SW5, SW6, SW7, SW8, SW9, SW10, SW11, SW12, SW13, SW14, SW15, SW16, SW18, SW19, SW20, SW21, SW22, SW23, SW24, SW25, SW26, SW27, SW28, SW29, SW31, SW33, SW34, SW35, SW36, SW37, SW38, SW39, SW40, SW41, SW42, SW43, SW44, SW46, SW48, SW49, SW50, SW51, SW52, SW54, SW55, SW56, SW57, SW58, SW60, SW62, SW63, SW64, SW65, SW66, SW68, SW69, SW70, SW71, SW72, SW74, SW76, SW77, SW81, SW83, SW84, SW85, SW86, SW87: SW_Push; SW_Cherry_MX_1.00u_PCB
SW17, SW30, SW61, SW73: SW_Push; SW_Cherry_MX_1.50u_PCB
SW32, SW45: SW_Push; SW_Cherry_MX_1.1666u_PCB
SW47, SW59: SW_Push; SW_Cherry_MX_1.6666u_PCB
SW53: SW_Push; SW_Cherry_MX_1.3333u_PCB
SW67: SW_Push; SW_Ch_Inv_MX_2.00u_PCB
SW75, SW78, SW80, SW82: SW_Push; SW_Cherry_MX_1.25u_PCB
SW79: SW_Push; SW_Ch_Inv_MX_6.00u_PCB_Stagger
U1: Elite-Pi

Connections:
+5V: U1.21 (VCC)
Col0: SW1.2, SW17.2, SW32.2, SW47.2, SW61.2, SW75.2, U1.1 (D0)
Col1: SW2.2, SW18.2, SW33.2, SW76.2, U1.2 (D1)
Col2: SW3.2, SW19.2, SW34.2, SW48.2, SW62.2, SW77.2, U1.5 (D2)
Col3: SW4.2, SW20.2, SW35.2, SW49.2, SW63.2, SW78.2, U1.6 (D3)
Col4: SW5.2, SW21.2, SW36.2, SW50.2, SW64.2, SW79.2, U1.7 (D4)
Col5: SW6.2, SW22.2, SW37.2, SW51.2, SW65.2, U1.8 (D5)
Col6: SW7.2, SW23.2, SW38.2, SW52.2, SW66.2, U1.9 (D6)
Col7: SW8.2, SW24.2, SW39.2, SW53.2, SW67.2, U1.13 (D21)
Col8: SW9.2, SW25.2, SW40.2, SW54.2, SW68.2, SW80.2, U1.14 (D23)
Col9: SW10.2, SW26.2, SW41.2, SW55.2, SW69.2, SW81.2, U1.15 (D20)
Col10: SW11.2, SW27.2, SW42.2, SW56.2, SW70.2, SW82.2, U1.16 (D22)
Col11: SW12.2, SW28.2, SW43.2, SW57.2, SW71.2, SW83.2, U1.17 (D26/A0)
Col12: SW13.2, SW29.2, SW44.2, SW58.2, SW72.2, SW84.2, U1.18 (D27/A1)
Col13: SW14.2, SW30.2, SW59.2, SW73.2, SW85.2, U1.19 (D28/A2)
Col14: SW15.2, SW45.2, SW86.2, U1.20 (D29/A3)
Col15: SW16.2, SW31.2, SW46.2, SW60.2, SW74.2, SW87.2, U1.11 (D8)
GND: R1.1, U1.3 (GND-D10), U1.4 (GND-D11), U1.23 (GND)
Led: D88.2 (A), U1.12 (D9)
unnamed: D1.2 (A), SW1.1
unnamed: D2.2 (A), SW2.1
unnamed: D3.2 (A), SW3.1
unnamed: D4.2 (A), SW4.1
unnamed: D5.2 (A), SW5.1
unnamed: D6.2 (A), SW6.1
unnamed: D7.2 (A), SW7.1
unnamed: D8.2 (A), SW8.1
unnamed: D9.2 (A), SW9.1
unnamed: D10.2 (A), SW10.1
unnamed: D11.2 (A), SW11.1
unnamed: D12.2 (A), SW12.1
unnamed: D13.2 (A), SW13.1
unnamed: D14.2 (A), SW14.1
unnamed: D15.2 (A), SW15.1
unnamed: D16.2 (A), SW16.1
unnamed: D17.2 (A), SW17.1
unnamed: D18.2 (A), SW18.1
unnamed: D19.2 (A), SW19.1
unnamed: D20.2 (A), SW20.1
unnamed: D21.2 (A), SW21.1
unnamed: D22.2 (A), SW22.1
unnamed: D23.2 (A), SW23.1
unnamed: D24.2 (A), SW24.1
unnamed: D25.2 (A), SW25.1
unnamed: D26.2 (A), SW26.1
unnamed: D27.2 (A), SW27.1
unnamed: D28.2 (A), SW28.1
unnamed: D29.2 (A), SW29.1
unnamed: D30.2 (A), SW30.1
unnamed: D31.2 (A), SW31.1
unnamed: D32.2 (A), SW32.1
unnamed: D33.2 (A), SW33.1
unnamed: D34.2 (A), SW34.1
unnamed: D35.2 (A), SW35.1
unnamed: D36.2 (A), SW36.1
unnamed: D37.2 (A), SW37.1
unnamed: D38.2 (A), SW38.1
unnamed: D39.2 (A), SW39.1
unnamed: D40.2 (A), SW40.1
unnamed: D41.2 (A), SW41.1
unnamed: D42.2 (A), SW42.1
unnamed: D43.2 (A), SW43.1
unnamed: D44.2 (A), SW44.1
unnamed: D45.2 (A), SW45.1
unnamed: D46.2 (A), SW46.1
unnamed: D47.2 (A), SW47.1
unnamed: D48.2 (A), SW48.1
unnamed: D49.2 (A), SW49.1
unnamed: D50.2 (A), SW50.1
unnamed: D51.2 (A), SW51.1
unnamed: D52.2 (A), SW52.1
unnamed: D53.2 (A), SW53.1
unnamed: D54.2 (A), SW54.1
unnamed: D55.2 (A), SW55.1
unnamed: D56.2 (A), SW56.1
unnamed: D57.2 (A), SW57.1
unnamed: D58.2 (A), SW58.1
unnamed: D59.2 (A), SW59.1
unnamed: D60.2 (A), SW60.1
unnamed: D61.2 (A), SW61.1
unnamed: D62.2 (A), SW62.1
unnamed: D63.2 (A), SW63.1
unnamed: D64.2 (A), SW64.1
unnamed: D65.2 (A), SW65.1
unnamed: D66.2 (A), SW66.1
unnamed: D67.2 (A), SW67.1
unnamed: D68.2 (A), SW68.1
unnamed: D69.2 (A), SW69.1
unnamed: D70.2 (A), SW70.1
unnamed: D71.2 (A), SW71.1
unnamed: D72.2 (A), SW72.1
unnamed: D73.2 (A), SW73.1
unnamed: D74.2 (A), SW74.1
unnamed: D75.2 (A), SW75.1
unnamed: D76.2 (A), SW76.1
unnamed: D77.2 (A), SW77.1
unnamed: D78.2 (A), SW78.1
unnamed: D79.2 (A), SW79.1
unnamed: D80.2 (A), SW80.1
unnamed: D81.2 (A), SW81.1
unnamed: D82.2 (A), SW82.1
unnamed: D83.2 (A), SW83.1
unnamed: D84.2 (A), SW84.1
unnamed: D85.2 (A), SW85.1
unnamed: D86.2 (A), SW86.1
unnamed: D87.2 (A), SW87.1
unnamed: D88.1 (K), R1.2
Row0: D1.1 (K), D2.1 (K), D3.1 (K), D4.1 (K), D5.1 (K), D6.1 (K), D7.1 (K), D8.1 (K), D9.1 (K), D10.1 (K), D11.1 (K), D12.1 (K), D13.1 (K), D14.1 (K), D15.1 (K), D16.1 (K), U1.29 (D16)
Row1: D17.1 (K), D18.1 (K), D19.1 (K), D20.1 (K), D21.1 (K), D22.1 (K), D23.1 (K), D24.1 (K), D25.1 (K), D26.1 (K), D27.1 (K), D28.1 (K), D29.1 (K), D30.1 (K), D31.1 (K), U1.28 (D15)
Row2: D32.1 (K), D33.1 (K), D34.1 (K), D35.1 (K), D36.1 (K), D37.1 (K), D38.1 (K), D39.1 (K), D40.1 (K), D41.1 (K), D42.1 (K), D43.1 (K), D44.1 (K), D45.1 (K), D46.1 (K), U1.27 (D14)
Row3: D47.1 (K), D48.1 (K), D49.1 (K), D50.1 (K), D51.1 (K), D52.1 (K), D53.1 (K), D54.1 (K), D55.1 (K), D56.1 (K), D57.1 (K), D58.1 (K), D59.1 (K), D60.1 (K), U1.26 (D13)
Row4: D61.1 (K), D62.1 (K), D63.1 (K), D64.1 (K), D65.1 (K), D66.1 (K), D67.1 (K), D68.1 (K), D69.1 (K), D70.1 (K), D71.1 (K), D72.1 (K), D73.1 (K), D74.1 (K), U1.25 (D12)
Row5: D75.1 (K), D76.1 (K), D77.1 (K), D78.1 (K), D79.1 (K), D80.1 (K), D81.1 (K), D82.1 (K), D83.1 (K), D84.1 (K), D85.1 (K), D86.1 (K), D87.1 (K), U1.10 (D7)

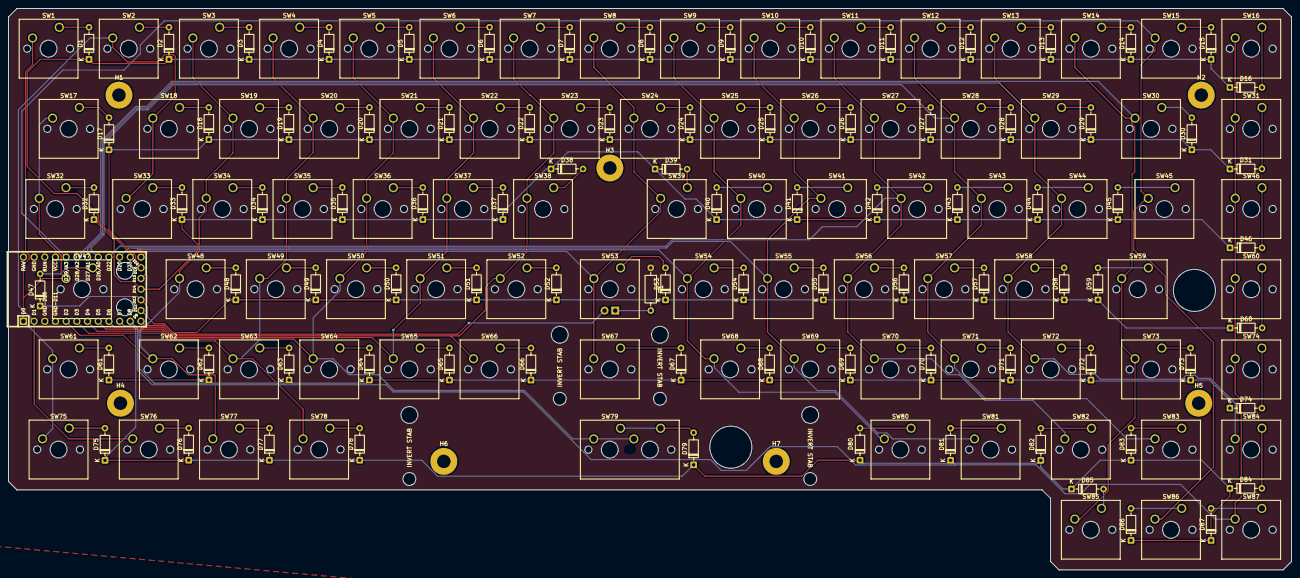
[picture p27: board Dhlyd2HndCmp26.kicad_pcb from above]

Board: 2 copper layers, 304.8 x 133.4 mm, 184 parts (0 on the bottom side), 112 nets.

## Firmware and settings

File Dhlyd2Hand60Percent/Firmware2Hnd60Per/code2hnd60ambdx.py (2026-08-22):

# Post-Mech 2-Hand Sixty Ambidextrous 2nd Layer by Dholydai 22 Aug 2026
import board

from kmk.kmk_keyboard import KMKKeyboard
from kmk.keys import KC
from kmk.scanners import DiodeOrientation
from kmk.extensions.lock_status import LockStatus
from kmk.extensions.LED import LED
# from kmk.modules.macros import Macros
# from kmk.modules.macros import Press, Release, Tap
from kmk.modules.layers import Layers

keyboard = KMKKeyboard()

keyboard.col_pins = (board.D0, board.D1, board.D2, board.D3, board.D4, board.D5,
                     board.D6, board.D21, board.D23, board.D20, board.D22, board.D26,
                     board.D27, board.D28,)
keyboard.row_pins = (board.D16, board.D15, board.D14, board.D13, board.D12,)
keyboard.diode_orientation = DiodeOrientation.COL2ROW

keyboard.modules.append(Layers())

LFN = KC.TG(1)
RFN = KC.TG(2)

keyboard.keymap = [
    # Base Layer 0
    [KC.ESC, KC.GRV, KC.N1, KC.N2, KC.N3, KC.N4, KC.N5, KC.N6, KC.N7, KC.N8,
     KC.N9, KC.N0, KC.LBRC, KC.RBRC,
     KC.BSLS, KC.SLSH, KC.QUOT, KC.COMM, KC.DOT, KC.P, KC.Y, KC.F, KC.G, KC.C,
     KC.R, KC.L, KC.MINS, KC.EQL,
     KC.BSPC, KC.A, KC.O, KC.E, KC.U, KC.I, KC.CAPS, KC.D, KC.H, KC.T, KC.N, KC.S,
     KC.NO, KC.ENT,
     KC.LSFT, KC.SCLN, KC.Q, KC.J, KC.K, KC.X, KC.TAB, KC.B, KC.M, KC.W,
     KC.V, KC.Z, KC.NO, KC.RSFT,
     KC.LCTL, LFN, KC.LGUI, KC.LALT, KC.NO, KC.NO, KC.SPC, KC.NO, KC.NO, KC.RALT,
     KC.LGUI, RFN, KC.NO, KC.RCTL,
     ],

    # Function Right 1
    [KC.TRNS, KC.TRNS, KC.F1, KC.F2, KC.F3, KC.F4, KC.F5, KC.F6, KC.F7, KC.F8,
     KC.F9, KC.F10, KC.F11, KC.F12,
     KC.TRNS, KC.TRNS, KC.TRNS, KC.TRNS, KC.TRNS, KC.TRNS, KC.TRNS, KC.PSCR,
     KC.SLCK, KC.PAUS, KC.TRNS, KC.TRNS, KC.TRNS, KC.TRNS,
     KC.DEL, KC.TRNS, KC.TRNS, KC.TRNS, KC.TRNS, KC.TRNS, KC.TRNS, KC.INS,
     KC.HOME, KC.PGUP, KC.TRNS, KC.TRNS, KC.NO, KC.TRNS,
     KC.TRNS, KC.TRNS, KC.TRNS, KC.TRNS, KC.TRNS, KC.TRNS, KC.TRNS, KC.DEL,
     KC.END, KC.PGDN, KC.TRNS, KC.UP, KC.NO, KC.TRNS,
     KC.TRNS, KC.TRNS, KC.TRNS, KC.TRNS, KC.NO, KC.NO, KC.TRNS, KC.NO, KC.NO,
     KC.TRNS, KC.LEFT, KC.DOWN, KC.NO, KC.RIGHT,
     ],

    # Function Left 2
    [KC.TRNS, KC.TRNS, KC.F1, KC.F2, KC.F3, KC.F4, KC.F5, KC.F6, KC.F7, KC.F8,
     KC.F9, KC.F10, KC.F11, KC.F12,
     KC.TRNS, KC.TRNS, KC.TRNS, KC.TRNS, KC.PSCR, KC.SLCK, KC.PAUS, KC.TRNS,
     KC.TRNS, KC.TRNS, KC.TRNS, KC.TRNS, KC.TRNS, KC.TRNS,
     KC.DEL, KC.TRNS, KC.TRNS, KC.INS, KC.HOME, KC.PGUP, KC.TRNS, KC.TRNS, KC.TRNS,
     KC.TRNS, KC.TRNS, KC.TRNS, KC.NO, KC.TRNS,
     KC.TRNS, KC.UP, KC.TRNS, KC.DEL, KC.END, KC.PGDN, KC.TRNS, KC.TRNS, KC.TRNS,
     KC.TRNS, KC.TRNS, KC.TRNS, KC.NO, KC.TRNS,
     KC.LEFT, KC.DOWN, KC.RIGHT, KC.TRNS, KC.NO, KC.NO, KC.TRNS, KC.NO, KC.NO,
     KC.TRNS, KC.TRNS, KC.TRNS, KC.NO, KC.TRNS,
     ],
]

# KMK does not currently support discrete (one color) layer indicator LEDs
leds = LED(led_pin=[board.D9, ])
# ledlft = LED(led_pin=[board.D7, ])
# ledrgt = LED(led_pin=[board.D8, ])



class LEDLockStatus(LockStatus):
    def set_lock_leds(self):
        if self.get_caps_lock():
            leds.set_brightness(75, leds=[0])
        else:
            leds.set_brightness(0, leds=[0])

    def after_hid_send(self, sandbox):
        super().after_hid_send(sandbox)  # Critically important. Do not forget
        if self.report_updated:
            self.set_lock_leds()

keyboard.extensions.append(leds)
keyboard.extensions.append(LEDLockStatus())

if __name__ == "__main__":
    keyboard.go()

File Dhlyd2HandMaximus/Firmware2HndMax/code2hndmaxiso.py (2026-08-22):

# Post-Mech 2-Hand Maximus (ISO) by Dholydai 22 Aug 2026
# For European (and other) languages that require a 48th character key
# A Dvorak scheme that requires a custom driver
import board

from kmk.kmk_keyboard import KMKKeyboard
from kmk.keys import KC
from kmk.scanners import DiodeOrientation
from kmk.extensions.lock_status import LockStatus
from kmk.extensions.LED import LED
from kmk.modules.macros import Macros
from kmk.modules.macros import Press, Release, Tap
from kmk.extensions.international import International

keyboard = KMKKeyboard()

keyboard.col_pins = (board.D0, board.D1, board.D2, board.D3, board.D4, board.D5,
                     board.D6, board.D21, board.D23, board.D20, board.D22,
                     board.D26, board.D27, board.D28, board.D29, board.D9,)
keyboard.row_pins = (board.D7, board.D8, board.D12, board.D13, board.D14, board.D15,
                     board.D16,)
keyboard.diode_orientation = DiodeOrientation.COL2ROW

macros = Macros()
keyboard.modules.append(macros)

COPY = KC.MACRO(
    Press(KC.LCTL),
    Tap(KC.C),
    Release(KC.LCTL)
)

CUT = KC.MACRO(
    Press(KC.LCTL),
    Tap(KC.X),
    Release(KC.LCTL)
)

PASTE = KC.MACRO(
    Press(KC.LCTL),
    Tap(KC.V),
    Release(KC.LCTL)
)

MENU = KC.MACRO(
    Press(KC.LSFT),
    Tap(KC.F10),
    Release(KC.LSFT)
)

keyboard.extensions.append(International())

keyboard.keymap = [
    [KC.ESC, KC.F1, KC.F2, KC.F3, KC.F4, KC.F5, KC.F6, KC.F7, KC.F8, KC.F9, KC.F10,
     KC.F11, KC.F12, KC.PSCR, KC.SLCK, KC.PAUS,
     KC.NUBS, KC.GRV, KC.N1, KC.N2, KC.N3, KC.N4, KC.N5, KC.N6, KC.N7, KC.N8, KC.N9,
     KC.N0, KC.MINS, KC.EQL, KC.INS, KC.HOME,
     KC.BSLS, KC.SLSH, KC.QUOT, KC.COMM, KC.DOT, KC.P, KC.Y, KC.F, KC.G, KC.C, KC.R,
     KC.L, KC.LBRC, KC.RBRC, KC.DEL, KC.END,
     KC.BSPC, KC.A, KC.O, KC.E, KC.U, KC.I, KC.CAPS, KC.D, KC.H, KC.T, KC.N, KC.S,
     KC.ENT, COPY, CUT, PASTE,
     KC.LSFT, KC.SCLN, KC.Q, KC.J, KC.K, KC.X, KC.TAB, KC.B, KC.M, KC.W, KC.V, KC.Z,
     KC.RSFT, KC.UP, KC.PGDN, KC.PGUP,
     KC.LCTL, KC.NO, KC.LGUI, KC.LALT, KC.NO, KC.NO, KC.SPC, KC.NO, KC.RALT, KC.RGUI,
     KC.MENU, KC.RCTL, KC.LEFT, KC.DOWN, KC.RGHT, KC.P0,
     KC.NLCK, KC.PSLS, KC.PAST, KC.PMNS, KC.P7, KC.P8, KC.P9, KC.PPLS, KC.P4, KC.P5,
     KC.P6, KC.P1, KC.P2, KC.P3, KC.PENT, KC.PDOT, ]
     ]

leds = LED(led_pin=[board.D10_GND, board.D11_GND])

class LEDLockStatus(LockStatus):
    def set_lock_leds(self):
        if self.get_caps_lock():
            leds.set_brightness(50, leds=[0])
        else:
            leds.set_brightness(0, leds=[0])

        if self.get_num_lock():
            leds.set_brightness(50, leds=[1])
        else:
            leds.set_brightness(0, leds=[1])

    def after_hid_send(self, sandbox):
        super().after_hid_send(sandbox)  # Critically important. Do not forget
        if self.report_updated:
            self.set_lock_leds()

keyboard.extensions.append(leds)
keyboard.extensions.append(LEDLockStatus())

if __name__ == '__main__':
    keyboard.go()

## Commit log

2025-01-12 OpenSCAD case design files
    [200SixtyBtmLft.scad, 200SixtyBtmRgt.scad, 200SixtyTopLft.scad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]
2025-01-12 Case design files
    [200SixtyBtmLft.stl, 200SixtyBtmRgt.stl, 200SixtyTopLft.stl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]
2025-01-12 3D model files
    [200SixtyBtmLft.stl, 200SixtyBtmRgt.stl, 200SixtyTopLft.stl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]
2025-01-12 Files to create the case
2025-01-12 PCB design files
    [Dhlyd2Hnd60Per.kicad_pcb, Dhlyd2Hnd60Per.kicad_sch]
2025-01-12 OpenSCAD case design file
    [200CompLeftBtmLft.scad, 200CompLeftBtmRgt.scad, 200CompLeftTopLft.scad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]
2025-08-01 Files to 3D print the case
2025-08-01 Open SCAD design files
    [SixtyBtmLft.scad, SixtyBtmRgt.scad, SixtyTopLft.scad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]
2025-08-01 OpenSCAD design files
    [Comp2HndBtmLft.scad, Comp2HndBtmRgt.scad, Comp2HndTopLft.scad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]
2026-07-24 3D print files
    [ResetRunCvr60.scad, SixtyBtmLft.scad, SixtyBtmRgt.scad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]
2026-07-24 3D model
    [ResetRunCvr60.stl, SixtyBtmLft.stl, SixtyBtmRgt.stl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]
2026-07-24 Case design
    [ResetRunCvr60.scad, SixtyBtmLft.scad, SixtyBtmRgt.scad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]
2026-07-24 Keyboard case
2026-07-24 PCB design
    [Dhlyd2HndSxty26.kicad_pcb, Dhlyd2HndSxty26.kicad_sch]
2026-07-24 Minimal case design
2026-07-30 Custom Microsoft drivers for several languages
2026-07-30 US (English) ISO driver for Microsoft
2026-07-30 US (English) driver for Microsoft
2026-07-30 Brazil (Portuguese) driver for Microsoft
2026-07-30 Czechia driver for Microsoft
2026-07-30 Denmark driver for Microsoft
2026-07-30 Czechia (Czech) driver for Microsoft
2026-07-30 Denmark (Danish) driver for Microsoft
2026-07-30 France (French) BÉPO driver for Microsoft
2026-07-30 Germany (German) driver for Microsoft
2026-07-30 Spain (Spanish) driver for Microsoft
2026-07-30 Keyboard drivers for several other languages
2026-07-30 Keyboard drivers for several languages
2026-08-31 Keyboard drivers for some languages
